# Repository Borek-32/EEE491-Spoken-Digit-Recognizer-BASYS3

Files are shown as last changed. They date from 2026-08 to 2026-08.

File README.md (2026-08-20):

# FPGA MFCC digit recognizer

This repository is the source-and-evidence release of an EEE491 fixed-point
spoken-digit recognizer for the Digilent Basys 3. The design acquires an
external ADC stream and implements the full feature/classification path in
VHDL:

```text
ADC/VAD -> Hann window -> 512-point FFT -> 32-channel Mel bank
        -> log2 approximation -> 8-coefficient DCT -> template comparator
```

The packaged hardware profile is the home-fabricated microphone/ADC board on
Pmod JC. `constraints/jc_homefab.xdc` is the only top-level constraint file in
the release. Generated Vivado projects, checkpoints, bitstreams, logs and
waveform databases are deliberately not versioned.

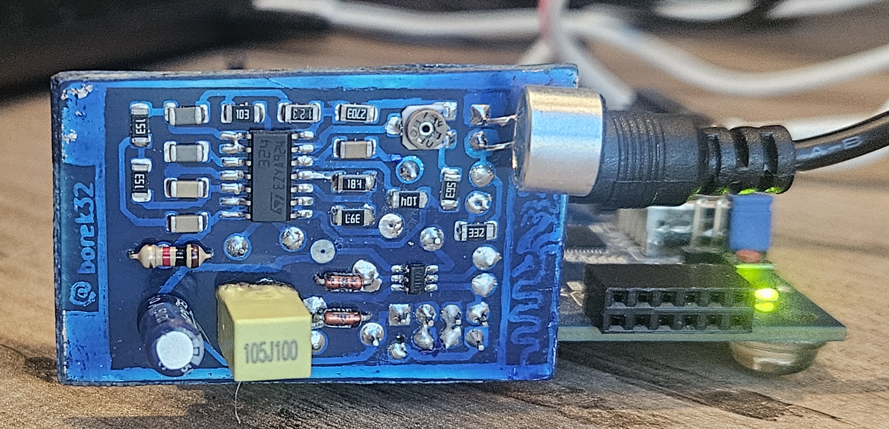
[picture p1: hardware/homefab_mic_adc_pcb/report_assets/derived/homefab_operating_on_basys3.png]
Home-fabricated input board operating with the Basys 3


## What is here

- `rtl/`: the eleven synthesizable VHDL units, with `top_module` as top.
- `testbench/` and `verification/`: eleven VHDL benches, retained fixed-point
  inputs/outputs, MATLAB cross-checks, and a bounded safe regression runner.
- `ip/` and `data/`: twenty AMD IP configuration files and five ROM
  initialization sources. Generated IP products are intentionally absent.
- `constraints/jc_homefab.xdc`: the complete 39-port Basys 3/JC pin profile.
- `hardware/homefab_mic_adc_pcb/`: KiCad sources, photos, verification tools,
  and report figures for the physical microphone/ADC board.
- `hardware/pcb_adc_uart/`: the isolated ADC-to-UART diagnostic and its
  explicitly bounded evidence.
- `implementation/`: retained text reports from the historical main
  run and the final JC-mapped implementation. These reports are evidence, not
  inputs to the clean build.
- `docs/report/EEE491_MFCC_Final_Report_2026-08-20.pdf`: the final project
  report.

## Quick start

Vivado 2025.2 is the reference version. Choose fresh directories outside this
repository; the scripts reject in-tree or pre-existing output directories.
Run Vivado itself from a fresh external runtime directory so journals, logs and
`.Xil` process state never enter the checkout.

```bash
repo_root=$(pwd -P)
build_dir=$(readlink -m ../mfcc-build-v1.0.0)
results_dir=$(readlink -m ../mfcc-results-v1.0.0)
runtime_dir=$(readlink -m ../mfcc-runtime-v1.0.0)
mkdir -- "$runtime_dir"

(
  cd "$runtime_dir"
  vivado -mode batch -notrace \
    -journal "$runtime_dir/01-recreate.jou" \
    -log "$runtime_dir/01-recreate.log" \
    -source "$repo_root/scripts/recreate_project.tcl" \
    -tclargs "$build_dir"

  vivado -mode batch -notrace \
    -journal "$runtime_dir/04-build-jc.jou" \
    -log "$runtime_dir/04-build-jc.log" \
    -source "$repo_root/scripts/build_jc_homefab.tcl" \
    -tclargs "$build_dir" "$results_dir" 4
)
```

The first command copies the release inputs into the external build directory,
creates a new project for `xc7a35tcpg236-1`, and regenerates IP products there.
The second runs synthesis and implementation, validates timing/routing/DRC and
the complete package-pin map, then places reports and a generated bitstream in
the external results directory.

Run the repository integrity and privacy gate with:

```bash
python3 scripts/check_release.py
```

The gate also requires Git's clean-filtered bytes to match the worktree bytes,
so a commit and fresh checkout cannot silently invalidate `SHA256SUMS`.

Or run the complete non-hardware release workflow in fresh external directories:

```bash
scripts/run_release_checks.sh ../mfcc-build-v1.0.0 \
  ../mfcc-results-v1.0.0 --top-smoke --jobs 4
```

`VIVADO_BIN` and `MATLAB_BIN` may name alternate executables. The wrapper runs
the integrity gate, recreation, nine safe XSim benches, optional top smoke,
MATLAB gates, and the full JC build. It creates the fresh external
`../mfcc-results-v1.0.0.runtime/` directory for Vivado process state and never
programs hardware. The MATLAB gate is serialized and refuses to start while
another MATLAB process is active.

See [REPRODUCIBILITY.md](REPRODUCIBILITY.md) for simulation, MATLAB, KiCad and
hardware procedures.

## Verified result and evidence boundary

The retained final JC implementation reports:

- routed setup slack `+0.671 ns` and hold slack `+0.020 ns`;
- 12,824/12,824 routable nets complete, with zero routing errors;
- zero DRC errors, critical warnings, or warnings (11 advisories);
- 5,603 LUTs, 8,437 registers, 23.5 BRAM tiles, and 15 DSPs.

Those are internal FPGA implementation results. The methodology report retains
36 `TIMING-18` warnings because external I/O delays were not characterized;
the ADC board interface is therefore not claimed as board-level timing closed.

The report describes a working bench demonstration and historical recognition
observations. No pre-labeled live session made with the final FFT/Mel-corrected
image was retained, so this release makes no numerical live-accuracy claim.
The earlier 30/30 development set predates those final corrections and is not
presented as final-system accuracy. Photographs show construction and operation;
they do not independently establish recognition accuracy.

The isolated ADC/UART reconstruction closes its declared internal timing, but
its retained CDC report contains 133 `CDC-1` critical findings, 12 `CDC-15`
warnings, and four `CDC-3` informational findings. Its corrected SPI-alignment
candidate passes simulation and implementation; the decisive voltage/UART
endpoint capture remains **NOT RUN**. These boundaries are preserved in the
corresponding hardware documentation.

## Hardware safety and explicit target selection

No script selects a programmer or serial port by a repository-embedded device
identifier. Programming requires both an explicit bitstream path and an
explicit JTAG target substring and the expected bitstream SHA-256. MATLAB
capture requires an explicit UART port, JTAG target identity, bitstream path,
expected SHA-256, programming-log path, and output path.
Inspect the discovered target and wiring before acting; a generated bitstream
or a successful JTAG configuration is not proof of correct analog behavior.

## License and citation

Original source and hardware-design files are released under the MIT License;
portfolio media, the report, retained evidence, and third-party tool/IP
material have the narrower terms described in [NOTICE.md](NOTICE.md). Citation
metadata is in [CITATION.cff](CITATION.cff).

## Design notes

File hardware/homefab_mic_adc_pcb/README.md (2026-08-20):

# Home-fabricated microphone and ADC PCB

This directory documents the physical input board used with the full MFCC
design on 19 August 2026. It combines the microphone front end, analog filter,
ADC121S101 interface, local adjustments, power connection, and a Basys 3 Pmod
connection.

## Retained configuration

- FPGA top: `top_module`
- ADC mapping: JC3/N17 `spi_clk`, JC4/P18 `spi_miso`, JC9/P17 `cs_out`
- Full debug stream: Basys 3 USB-UART TX on A18 at 1,000,000 baud
- Canonical constraint: `../../constraints/jc_homefab.xdc`
- Routed implementation evidence: `../../implementation/jc_homefab/`
- Photographs: `photos/`
- Reconciled board source and checks: `kicad/`
- Metadata-free report figures and generator: `report_assets/`

No bitstream or programming log is versioned. Build a fresh bitstream outside
the repository and pass its path, SHA-256 and an explicitly inspected JTAG
target substring to `programming/program_full_mfcc_jc.tcl`.

## Recognition evidence boundary

Bench operation and near-perfect informal recognition were observed during
development, but no pre-labeled live session made with the final FFT/Mel-
corrected image was retained. This release therefore makes no numerical
final-system accuracy claim. The logger under `../../verification/hardware/`
can create a new declared session, but a future run is new evidence and is not
retroactively part of the final report.

## KiCad boundary

The reconciled schematic and PCB share the same exact set of 21 named nets.
KiCad's native connectivity accounts for 75 pads, 287 track segments and 18
vias; one isolated Pmod pad intentionally remains no-net. The home-fabricated
copper is mirrored relative to logical ADC121S101 and LM324 footprint numbering,
as documented in `kicad/README.md`.

Net reconciliation passes, but fab-ready closure is not claimed. The retained
PCB DRC has 12 errors and 114 warnings; schematic ERC has 8 errors and 20
warnings. JC10/R18 is also driven by the FPGA `pmod` output and must remain
physically isolated from an unintended board connection.

## Photograph provenance

The eleven retained photographs cover the July-to-August fabrication sequence.
The repository copies were auto-oriented and stripped of EXIF/GPS metadata.
The July defective UV trial is explicitly development evidence; later operating,
component-side and solder-side images document the final populated board.
Photographs do not independently establish electrical behavior or recognition
accuracy.

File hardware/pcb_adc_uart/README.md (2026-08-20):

# Standalone PCB ADC-to-UART diagnostic

This directory isolates the recovered `PCB.vhd` diagnostic from the MFCC
recognizer. Top `PCB` reads the external SPI ADC, averages 32 conversions,
recenters the 12-bit samples, and transmits signed 16-bit values over the
Basys 3 USB-UART connection.

## Reproducible inputs

- `src/PCB.vhd`: recovered baseline RTL, SHA-256
  `751c59a1592b73d9a1a77779d09f4339b96f97ef051685ae126386492618f96f`
- `constraints/pcb_adc_uart_basys3.xdc`: standalone JC constraints
- `ip/clk_wiz_0/clk_wiz_0.xci`: 100 MHz to 36 MHz Clocking Wizard metadata
- `recreate_project.tcl` and `build_and_verify.tcl`: out-of-tree interfaces
- `build_evidence/`: retained text reports from the 19 August reconstruction
- `trials/adc121s101_spi_alignment_20260819/`: preserved baseline/candidate
  source comparison and explicitly bounded evidence

Generated XPR, IP products, DCP, bitstream, log and cache files are excluded.

## Recreate and build

Choose fresh directories outside the public repository:

```bash
vivado -mode batch -notrace -source recreate_project.tcl \
  -tclargs ../../../../pcb-adc-build
vivado -mode batch -notrace -source build_and_verify.tcl \
  -tclargs ../../../../pcb-adc-build ../../../../pcb-adc-results 4
```

An optional second recreation argument selects an explicit RTL file. This is
how the retained SPI-alignment candidate can be rebuilt without replacing the
baseline source:

```bash
vivado -mode batch -notrace -source recreate_project.tcl \
  -tclargs ../../../../pcb-adc-candidate-build \
  trials/adc121s101_spi_alignment_20260819/candidate/PCB.vhd
```

The scripts refuse in-tree or pre-existing output directories. The build gate
checks routed setup/hold timing, complete routing, DRC, methodology, the 100 MHz
and 36 MHz clocks, and the exact eight-port package-pin map. A generated
bitstream is copied only to the external results directory.

## Retained reconstruction result

Vivado 2025.2 reported WNS `+6.899 ns`, WHS `+0.131 ns`, all 203 routable nets
complete, and zero DRC/methodology findings. That is internal implementation
evidence, not complete hardware validation. The external SPI ports have no
ADC-datasheet-derived input/output delays.

The retained CDC report still contains 133 `CDC-1` critical findings, 12
`CDC-15` warnings and four `CDC-3` informational findings for asynchronous
buttons/reset and the handshake-held sample transfer. This recovered design is
not claimed CDC-clean. Hardware capture was not rerun for the reconstruction.

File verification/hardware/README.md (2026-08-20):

# Live MFCC hardware capture

These MATLAB functions parse the `top_module` debug protocol at 1,000,000 baud.
They are distinct from the standalone 921,600-baud ADC/UART diagnostic.

No final labeled accuracy session is included. To create a new session, first
build and program a fresh JC bitstream, retain the programming transcript, and
provide every machine-specific value explicitly:

```matlab
cd('verification/hardware')
run_live_accuracy_session(10, uartPort, jtagTarget, bitPath, ...
    expectedBitSha256, programmingLogPath, evidenceOutputDirectory)
```

The launcher requires a nonempty UART port and JTAG target identity, verifies
the exact bitstream hash, checks a recent PASS programming record, and refuses
post-result retries. It pre-generates a balanced randomized schedule of 100
declared trials (ten per digit) by default. For each prompt, the operator arms
the UART and then starts one spoken-digit acquisition.

A completed session contains the schedule and metadata, raw bytes and decoded
MAT data for each trial, append-after-every-trial CSV, per-digit metrics, a
confusion matrix with a separate protocol-failure column, a summary, logger
source snapshot, programming provenance, lifecycle index, and SHA-256 manifest.
The primary metric is correct/planned; conditional correct/protocol-complete and
transport completion are reported separately.

Run the non-hardware evidence-path self-test with:

```matlab
run_live_accuracy_session("selftest")
```

Each live trial contains 63 frames. Each frame contains 1,362 big-endian 32-bit
words: marker/address/COMP status, 512 ADC words, 512 WINDOW words, 256 FFT
words, 32 MEL words, 32 LOGMEL words, eight DCT words, and the end marker. The
decision is accepted only from frame address 15,872.

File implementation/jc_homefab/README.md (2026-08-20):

# Retained JC/home-fabricated-board implementation evidence

This directory contains sanitized text evidence from the isolated Vivado 2025.2
implementation completed on 19 August 2026. The public build input is
`../../constraints/jc_homefab.xdc`; the reports here are not consumed during a
clean rebuild.

## Pin profile

| Signal | Basys 3 contact | Package pin | Direction |
| --- | --- | --- | --- |
| `spi_clk` | JC3 | N17 | output |
| `spi_miso` | JC4 | P18 | input |
| `cs_out` | JC9 | P17 | output |

The XDC is a complete 39-port profile, not an overlay. JC10/R18 remains driven
by the separate `pmod` output and must be physically isolated unless a future
board revision makes that connection intentionally compatible.

## Retained result

- Top `top_module`, part `xc7a35tcpg236-1`
- Implementation through `write_bitstream`: complete
- WNS `+0.671 ns`; WHS `+0.020 ns`
- 12,824/12,824 routable nets routed; zero routing errors
- DRC: 0 errors, 0 critical warnings, 0 warnings, 11 advisories
- 5,603 LUTs, 8,437 registers, 23.5 BRAM tiles, 15 DSPs
- All 39 scalarized ports constrained exactly once

The public release excludes the generated `.bit`, routed `.dcp`, Vivado logs,
IP-status dump, and original-tree protection hashes. Rebuild with
`../../scripts/recreate_project.tcl` and `../../scripts/build_jc_homefab.tcl`;
generated results remain outside the checkout.

## Evidence boundary

This is an internal FPGA implementation PASS. It is not external ADC timing
closure or a standalone hardware-function proof. The methodology report retains
36 `TIMING-18` warnings for 18 inputs and 18 outputs without I/O delays. The
full MFCC design also retains the legacy ADC receiver; the isolated diagnostic's
corrected SPI candidate is not silently substituted here.

Machine-local command paths in these retained text reports were replaced with
`<isolated-build>` for publication. Numerical findings and report bodies were
otherwise retained.

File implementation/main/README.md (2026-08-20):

# Historical main implementation reports

These four text reports preserve the routed result from the finalized main
project before public-repository reconstruction. They record WNS `+0.630 ns`,
WHS `+0.014 ns`, complete routing, and routed DRC/utilization data.

No corresponding baseline constraint file is packaged: the only public build
profile is `../../constraints/jc_homefab.xdc`. These reports are historical
evidence, not inputs to `scripts/recreate_project.tcl`, and must not be read as
proof of ADC board-level timing because 36 `TIMING-18` missing-I/O-delay
warnings remain in the timing summary.

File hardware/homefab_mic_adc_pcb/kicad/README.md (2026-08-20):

# Reconciled KiCad source

This directory contains the report-ready schematic and the recovered PCB with
every routed copper island assigned its schematic net name; the one physically
isolated, unused Pmod pad is explicitly retained as `<no net>`.

- `mfcc_homefab_named_nets.kicad_sch`: schematic with the ADC ground joined to
  the existing global `GND` net.
- `mfcc_homefab_named_nets.kicad_pcb`: original board geometry with net names
  added to all pads, routed segments, and vias.
- `mfcc_homefab_named_nets.kicad_pro`: KiCad project settings generated for the
  reconciled pair.
- `tools/`: fail-closed reconstruction and verification scripts.
- `evidence/`: exported netlist, IPC-D-356 netlist, native KiCad checks,
  hashes, and the inspected schematic render.

The pre-reconciliation source copies are retained under `originals/`. Their
SHA-256 values are:

- schematic: `e35c51a3030d64c75fbf8b99cae6bb0e8106192cca6c8ed2968b3d3029f0215c`
- PCB: `d63a80d06c6ad783caed415275df6e86c6c870cf5f2c0cff97cd489689012f88`

## Exact net reconciliation

KiCad 10.0.3 native connectivity found 22 physical copper islands. Twenty-one
use the exact exported schematic names; the remaining island is an intentionally
isolated Pmod pad and remains `<no net>`.

| Island | Exact net | Pads | Segments | Vias |
| --- | --- | ---: | ---: | ---: |
| I001 | `/ref` | 4 | 12 | 0 |
| I002 | `/3v3` | 4 | 26 | 3 |
| I003 | `/JC9` | 2 | 33 | 4 |
| I004 | `GND` | 12 | 50 | 3 |
| I005 | `<no net>` | 1 | 0 | 0 |
| I006 | `/JC4` | 3 | 9 | 2 |
| I007 | `VCC` | 5 | 33 | 2 |
| I008 | `/JC3` | 2 | 4 | 1 |
| I009 | `/filter-out` | 4 | 13 | 1 |
| I010 | `/div-ref` | 4 | 14 | 0 |
| I011 | `/mic` | 3 | 15 | 2 |
| I012 | `/ss2r` | 3 | 6 | 0 |
| I013 | `/div-out` | 3 | 8 | 0 |
| I014 | `/ss2c` | 3 | 8 | 0 |
| I015 | `/amp1` | 3 | 10 | 0 |
| I016 | `/pot1` | 2 | 6 | 0 |
| I017 | `/ss1c` | 3 | 8 | 0 |
| I018 | `/ss1o` | 4 | 10 | 0 |
| I019 | `/amp2` | 2 | 7 | 0 |
| I020 | `/amp-out` | 3 | 4 | 0 |
| I021 | `/ss1r` | 3 | 8 | 0 |
| I022 | `/pot2` | 2 | 3 | 0 |

The exported schematic contains exactly these 21 named nets, and the named PCB
contains the same 21-name set. Coverage is complete: 75 pads, 287 track
segments, and 18 vias are accounted for. The before/after structured geometry
fingerprints are identical.

## Home-fabrication mirror

The successful physical board is mirrored relative to the logical pad numbers
in the recovered footprints. Net assignment therefore follows the working
electrical pins, not the printed geometric pad numbers.

ADC footprint geometry maps to the
[TI ADC121S101 pinout](https://www.ti.com/lit/ds/symlink/adc121s101.pdf)
as follows:

| Geometric pad | Actual ADC pin/function | Net |
| ---: | --- | --- |
| 1 | 3, `VIN` | `/ref` |
| 2 | 2, `GND` | `GND` |
| 3 | 1, `VA` | `/3v3` |
| 4 | 6, `/CS` | `/JC9` |
| 5 | 5, `SDATA` | `/JC4` |
| 6 | 4, `SCLK` | `/JC3` |

For the SO-14 LM324, the actual lead is `15 - geometric pad`. This places the
actual positive supply on geometric pad 11 (`VCC`) and the actual negative
supply on geometric pad 4 (`GND`), and it resolves all four amplifier stages.
The two recovered board diode references are also reversed by role relative to
the schematic; the net assignment follows the electrical clamp nodes.

## Ground correction

The source schematic used both the global `GND` net and a local `/gnd` label
for the ADC. The fabricated PCB has one common ground island. The reconciled
schematic therefore replaces only that local label with a wired global GND
symbol. It now exports one `GND` net and no `/gnd` or anonymous ADC-ground net.

## Verification boundary

`evidence/bundle_validation.json` records `PASS_NET_ASSIGNMENT`:

- 21/21 schematic names equal 21/21 named PCB nets;
- all pads, tracks, and vias are assigned to their native KiCad island;
- one isolated Pmod pad is deliberately left no-net;
- no board geometry changed;
- KiCad DRC reports zero unconnected items.

This does **not** make the legacy home-fabrication layout DRC-clean. The retained
DRC contains 126 inherited findings: 12 errors and 114 warnings, including two
copper-clearance findings, malformed/co-located Pmod holes, courtyard overlaps,
a missing formal `Edge.Cuts` outline, and dangling legacy stubs. The schematic
ERC retains 28 pre-existing structural findings (8 errors and 20 warnings),
principally because the drawing models four op-amp triangles as separate
references rather than one multi-unit LM324 package and omits connector/power
driver detail. These limitations are preserved rather than hidden.

The direct Pmod footprint also joins the geometric contacts corresponding to
JC4 and JC10. The full FPGA design still drives JC10 as a separate `pmod`
output, so that contact must remain physically unpopulated/isolated or the FPGA
constraint must be disabled before treating a future revision as fab-ready.

## Reproduce the checks

Run the net assignment with KiCad's Python runtime:

```bash
flatpak run --command=python3 org.kicad.KiCad \
  tools/assign_schematic_nets.py SOURCE.kicad_pcb OUTPUT.kicad_pcb \
  --manifest evidence/net_assignment_manifest.json
```

Then export the schematic netlist/ERC and PCB DRC with `kicad-cli`, and run:

```bash
python3 tools/verify_named_bundle.py . \
  --desktop-schematic originals/mfcc.kicad_sch \
  --desktop-board originals/mfccsmd.kicad_pcb \
  --output evidence/bundle_validation.json
```

`PASS_NET_ASSIGNMENT` is deliberately narrower than fabrication approval. The
retained 126 PCB DRC and 28 schematic ERC findings remain open. Machine-local
paths in the exported evidence were replaced with repository-relative names;
the visible `borek32` copper marking is retained as intentional attribution.

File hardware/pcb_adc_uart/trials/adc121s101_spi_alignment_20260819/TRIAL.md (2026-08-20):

# ADC121S101 SPI-alignment trial (19 August 2026)

## Status

**Simulation PASS; implementation PASS; historical JTAG configuration PASS;
ADC endpoint capture NOT RUN.** This isolated diagnostic did not modify the
full MFCC `rtl/ADC.vhd`.

## Hypothesis and candidate

Bench observations near -2048 counts at 0 V but near 0 around the ADC supply
were consistent with a lost most-significant bit. The recovered receiver made
CS and the first falling SCLK edge coincide, did not explicitly retain a full
16-edge frame, and could sample before the ADC's worst-case access time.

The candidate in `candidate/PCB.vhd` asserts CS before the first transition,
captures exactly 16 falling edges, keeps the final 12 straight-binary bits,
discards the first completed conversion after start, averages the next 32, and
subtracts 2048 once. Its SHA-256 is
`a0171a70c302a14324324ea2dcbe9c7db5a120b0992fcf97e270fb91682063c6`.
The baseline source SHA-256 is
`751c59a1592b73d9a1a77779d09f4339b96f97ef051685ae126386492618f96f`.

## Retained results

The purpose-built model used worst-case 3.3 V `tACC=40 ns`, optional leading
zero phase behavior, exact 16-edge framing, a nontrivial discarded frame, and
six 32-frame endpoint groups. The candidate returned centered values `-2048,
-2047, -1, 0, 1, 2047` for raw codes `000, 001, 7FF, 800, 801, FFF`; the
baseline failed the same checks. See `results/SIMULATION_RESULTS.md`.

The retained Vivado 2025.2 reports show WNS `+6.874 ns`, WHS `+0.106 ns`,
192/192 routable nets complete, zero DRC/methodology findings, the 100 MHz and
36 MHz clocks, and the JC mapping N17/P18/P17. External ADC input timing remains
unclosed, and inherited CDC findings remain disclosed.

Historical evidence recorded successful FPGA configuration of the candidate.
The public release removes the machine-specific JTAG identity, programming log,
bitstream, checkpoint and waveform/log products. A repeat must rebuild the
candidate, supply an explicit target and hash to `hardware/program_candidate.tcl`,
and retain new evidence outside the checkout.

## Evidence boundary

No measured `VA`, `Vin`, or raw UART endpoint capture was retained. Functional
ADC validation is therefore **NOT RUN**, not inferred from simulation,
implementation, or JTAG configuration. The decisive future measurements remain
0 V, measured midscale, and approximately `VA - 50 mV`, following
`results/HARDWARE_TEST_PROCEDURE.md`.

The timing/framing criteria follow the TI ADC121S101 Rev. H datasheet, especially
Figure 2 and Sections 8.3, 8.3.1, 8.3.2, and 8.4.2.

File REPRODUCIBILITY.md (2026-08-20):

# Reproducibility guide

This release separates reproducible inputs from retained historical evidence.
The clean scripts create all Vivado state outside the repository. Existing
reports under `implementation/` are never consumed by the build.

## Reference environment

The release was curated against:

- AMD Vivado 2025.2, build 6299465, IP build 6300035;
- MATLAB R2025b Update 5 (`25.2.0.3177638`);
- KiCad 10.0.3;
- Git 2.53.0;
- Python 3.14.4.

The FPGA part is `xc7a35tcpg236-1`. The clean Vivado recreation does not depend
on an installed Basys 3 board-part definition.

## 1. Verify the release

From the repository root:

```bash
python3 scripts/check_release.py
```

This checks the allowlisted source counts, required files, absence of generated
Vivado products and private machine identifiers, KiCad evidence boundary, Git
clean-filter byte stability for every manifest candidate, and every entry in
`SHA256SUMS`. Run it from a Git working tree so `.gitattributes` can be applied.
Maintainers may regenerate the portable manifest only after an intentional
content change:

```bash
python3 scripts/check_release.py --write-checksums
python3 scripts/check_release.py
```

Paths in `SHA256SUMS` are sorted repository-relative POSIX paths. The manifest
does not include itself or `.git/`.

### Complete non-hardware workflow

The documented steps below are also available through one fail-closed wrapper:

```bash
scripts/run_release_checks.sh ../mfcc-build-v1.0.0 \
  ../mfcc-results-v1.0.0 --top-smoke --jobs 4
```

`--top-smoke` is opt-in; omit it to retain an explicit `TOP_SMOKE=NOT_RUN`
boundary. Set `VIVADO_BIN=/path/to/vivado` or `MATLAB_BIN=/path/to/matlab` to
override the default `vivado` and `matlab` commands. Both supplied output paths
and the derived `RESULTS_DIR.runtime` path must be fresh and outside the
repository. The wrapper keeps Vivado's journals, logs and `.Xil` process state
in that runtime directory. It also refuses to overlap the MATLAB gate with an
existing MATLAB process and serializes concurrent wrapper invocations with a
per-user runtime lock. Physical programming is never part of this workflow.

## 2. Recreate the full JC project

Choose build, results and process-runtime paths outside the checkout that do
not already exist. The standalone commands in the following sections share
these absolute shell variables:

```bash
repo_root=$(pwd -P)
build_dir=$(readlink -m ../mfcc-build-v1.0.0)
results_dir=$(readlink -m ../mfcc-results-v1.0.0)
runtime_dir=$(readlink -m ../mfcc-runtime-v1.0.0)
mkdir -- "$runtime_dir"

(
  cd "$runtime_dir"
  vivado -mode batch -notrace \
    -journal "$runtime_dir/01-recreate.jou" \
    -log "$runtime_dir/01-recreate.log" \
    -source "$repo_root/scripts/recreate_project.tcl" \
    -tclargs "$build_dir"
)
```

The script copies `rtl/`, `testbench/`, `constraints/` and `verification/` into
`../mfcc-build-v1.0.0/`. It stages byte-for-byte `ip/` and `data/`
under the external compatibility path
`../mfcc-build-v1.0.0/mfcc-recog 1.4.srcs/sources_1/`; Vivado validates that
original XCI customization context and the relative COE paths. It then creates
a fresh project, sets VHDL 2008, adds only `constraints/jc_homefab.xdc`, and
reapplies each resolved COE path plus the defining multiplier and FFT
customizations through Vivado's IP API to initialize fresh model state. Vivado
writes the same relative COE values back into the external XCI copies before
regenerating IP. The script refuses to overwrite an existing directory or
build inside the repository.

## 3. Run the bounded behavioral regression

After project recreation:

```bash
(
  cd "$runtime_dir"
  vivado -mode batch -notrace \
    -journal "$runtime_dir/02-safe-testbenches.jou" \
    -log "$runtime_dir/02-safe-testbenches.log" \
    -source "$repo_root/verification/run_testbenches.tcl" \
    -tclargs "$build_dir"
)
```

The default safe set is `tb_CTRL`, `tb_debug`, `tb_WINDOW`, `tb_FFT`, `tb_MEL`,
`tb_LOGMEL`, `tb_DCT`, `tb_comp`, and `tb_seven_segment`. Each bench is bounded
to 20 ms simulated time, and the runner scans XSim's transcript before printing
PASS. `tb_ADC` is rejected by this interface because its long acquisition run
needs an explicitly monitored workflow. `tb_top_module` remains opt-in:

```bash
(
  cd "$runtime_dir"
  vivado -mode batch -notrace \
    -journal "$runtime_dir/03-top-smoke.jou" \
    -log "$runtime_dir/03-top-smoke.log" \
    -source "$repo_root/verification/run_testbenches.tcl" \
    -tclargs "$build_dir" tb_top_module
)
```

Testbench outputs are written beneath the external project's
`verification/tb_output/`, not into the checkout.

Run the matching MATLAB fixed-point checks against that external snapshot:

```bash
matlab_lock=${XDG_RUNTIME_DIR:-/tmp}/mfcc-release-matlab-$(id -u).lock
matlab_log="$runtime_dir/matlab-safe.log"
(
  set -euo pipefail
  if ! flock -n 9; then
    echo "another MFCC release MATLAB gate is active" >&2
    exit 2
  fi
  if pgrep -x MATLAB >/dev/null 2>&1; then
    echo "another MATLAB process is active; wait before running this gate" >&2
    exit 2
  fi
  cd "$build_dir"
  if ! matlab -batch \
    "run('verification/matlab/run_safe_module_verifiers.m'); diary('off'); clear cleanup_diary cleanup_state; fprintf('MATLAB_CALLER_CLEANUP_PASS\n');" \
    2>&1 | tee "$matlab_log"; then
    echo "MATLAB verification process failed" >&2
    exit 1
  fi
  grep -Fqx 'SAFE_MODULE_VERIFIERS_PASS count=9' "$matlab_log"
  grep -Fqx 'MATLAB_CALLER_CLEANUP_PASS' "$matlab_log"
) 9>"$matlab_lock"
```

The FFT checker uses the AMD bit-accurate model packaged with Vivado. Source
the Vivado settings script first, set `VIVADO_ROOT=/path/to/Vivado`, or use the
complete wrapper, which infers that root from an explicit `VIVADO_BIN` path.
The post-`run` cleanup must remain in the batch caller: MATLAB R2025b can abort
during process teardown if the suite's cleanup guards survive that boundary.
The process must exit zero and emit both required PASS markers. Do not run
another MATLAB process concurrently with this verification workload.

The retained `verification/tb_output/` files are historical reference evidence.
A fresh regression should be judged from the external build snapshot.

## 4. Synthesize, implement and validate

Use the fresh results path declared in step 2:

```bash
(
  cd "$runtime_dir"
  vivado -mode batch -notrace \
    -journal "$runtime_dir/04-build-jc.jou" \
    -log "$runtime_dir/04-build-jc.log" \
    -source "$repo_root/scripts/build_jc_homefab.tcl" \
    -tclargs "$build_dir" "$results_dir" 4
)
```

The optional final argument is the positive Vivado job count. The script:

1. resets and runs synthesis and implementation through `write_bitstream`;
2. writes timing, routing, DRC, methodology, utilization, I/O, clocks, CDC and
   timing-check reports outside the repository;
3. requires non-negative routed setup and hold slack;
4. requires every routable net to be routed;
5. rejects DRC error, critical-warning, or warning severity;
6. validates the exact 39-port package-pin dictionary and the 100 MHz clock;
7. copies the generated `.bit` only to the external results directory.

The external-interface limitation remains: the XDC constrains the internal
100 MHz clock but contains no ADC-datasheet-derived input/output delays.

## 5. KiCad evidence

The public `kicad/originals/` copies and reconciled pair are sufficient to rerun
the net assignment and verification. The visible decorative copper username is
retained as intentional public attribution; machine-local filesystem paths are
sanitized. See the directory README for commands and exact limits.

KiCad's Python runtime can rebuild the named-net PCB:

```bash
cd hardware/homefab_mic_adc_pcb/kicad
flatpak run --command=python3 org.kicad.KiCad \
  tools/assign_schematic_nets.py \
  originals/mfccsmd.kicad_pcb mfcc_homefab_named_nets.kicad_pcb \
  --manifest evidence/net_assignment_manifest.json
```

Run the fail-closed bundle verifier after exporting current KiCad netlist,
ERC, DRC and render artifacts as described in the local README:

```bash
python3 tools/verify_named_bundle.py . \
  --desktop-schematic originals/mfcc.kicad_sch \
  --desktop-board originals/mfccsmd.kicad_pcb \
  --output evidence/bundle_validation.json
```

`PASS_NET_ASSIGNMENT` means exact net-name coverage only. It is not a claim of
fab-ready DRC/ERC closure.

## 6. Hardware programming and capture

Build first, then inspect the live hardware target. Programming is deliberately
separate from implementation and is never performed by the build script:

```bash
(
  cd "$runtime_dir"
  vivado -mode batch -notrace \
    -journal "$runtime_dir/05-program-jc.jou" \
    -log "$runtime_dir/05-program-jc.log" \
    -source "$repo_root/hardware/homefab_mic_adc_pcb/programming/program_full_mfcc_jc.tcl" \
    -tclargs "$results_dir/top_module_jc_homefab.bit" \
    YOUR_EXPLICIT_JTAG_TARGET_SUBSTRING \
    YOUR_EXPLICIT_64_HEX_BITSTREAM_SHA256
)
```

The programming script requires and validates the selected bitstream's SHA-256.
It requires exactly one target match and exactly one `xc7a35t` device.

For a new labeled accuracy session, call MATLAB with all environment-specific
inputs. The output directory must be fresh and outside the repository:

```matlab
run_live_accuracy_session(10, uartPort, jtagTarget, bitPath, ...
    expectedBitSha256, programmingLogPath, evidenceOutputDirectory)
```

No retained final-system session is shipped. A newly generated session is new
evidence and must not be confused with the historical claims in the report.

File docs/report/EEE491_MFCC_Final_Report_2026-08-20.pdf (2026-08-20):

EEE491 ENGINEERING PROJECT REPORT

# FPGA-Based MFCC Spoken Digit Recognition

## A fixed-point audio feature-extraction and template-matching system for the Basys 3

Author: Kerem Gürbüz
Bilkent University, Department of Electrical and Electronics Engineering Target device: Digilent Basys 3 / xc7a35tcpg236-1 Project scope: RTL, verification, FPGA integration, and home-fabricated microphone/ADC PCBs Design language: VHDL
Tool flow: Vivado 2025.2, XSim, MATLAB Design baseline: implemented and routed Basys 3 system Repository: https://github.com/Borek-32/EEE491-Spoken-Digit-Recognizer-BASYS3 Final report - 20 August 2026

The report follows the complete path from signal acquisition to fixed-point recognition and physical prototyping.

FPGA MFCC Spoken Digit Recognition - EEE491

## Abstract

I built a fixed-point spoken-digit recognizer for the Digilent Basys 3. The design records 16,384 ADC samples, processes 63 overlapping frames, and extracts eight DCT coefficients using Hann windowing, a 512-point FFT, 32 MEL filters, and fixed-point log compression. In record mode, the FPGA writes a selected 16-frame feature sequence into writable reference RAM; in compare mode, a SAD/L1 engine searches the stored templates. A configuration-time seed containing 30 default templates allows immediate comparison before speaker-specific slots are recorded. The non-ADC stages are checked with XSim and integer models, and the current routed design meets the internal 100 MHz constraint. A 30-utterance development set separates 30/30 in leave-one-out testing, but those recordings predate the final FFT/MEL address corrections and are not a live-speaker accuracy result. I also designed and fabricated the microphone front-end PCB. On 19 August 2026 I also integrated a later home-fabricated microphone/ADC PCB through Pmod JC, programmed the corresponding full-design bitstream, and observed live recognition. Because no pre-labeled trial session was retained, I report that result as a functional bench observation rather than a numerical hardware accuracy claim. Keywords: FPGA; MFCC; fixed-point DSP; spoken digit recognition; VHDL; UART debugging.

## Contents

1 | Introduction and Project Objective | 4
2 | Design Boundary and Evidence Strategy | 6
3 | Hardware Platform and User Operation | 7
4 | System Architecture and Data Contracts | 8
5 | CTRL: Pipeline Orchestration | 10
6 | ADC: Acquisition, Averaging, and Voice Detection | 13
7 | WINDOW: Frame Extraction and Hann Multiplication | 16
8 | FFT: AXI4-Stream Transform and Power Spectrum | 18
9 | MEL: Perceptual Filter-Bank Accumulation | 22
10 | LOGMEL: Piecewise Logarithmic Compression | 26
11 | DCT: Eight-Coefficient Feature Compression | 30
12 | COMP: Runtime Enrollment, Active-Window Selection, and Template Matching | 32
13 | DEBUG: UART Observability | 41
14 | Seven-Segment Display and Top-Level Integration | 42
15 | Verification Methodology and Module Results | 44
16 | Programmed-Board Debugger Demonstration | 45
17 | Retained FPGA-Computed Spoken-Digit Outputs and Separability Results | 53
18 | Vivado Implementation and Clock Engineering | 62
19 | Analog Front End and PCB Development | 64
20 | Discussion, Limitations, and Conclusion | 87
21 | References | 90
A | Supplementary Testbench Views | 91
B | Complete Programmed-Board Tone Evidence | 97
C | Evidence Labels and Reproduction Guide | 111

## 1 Introduction and Project Objective

This project asked me to implement spoken-digit recognition on an FPGA, including acquisition, frame control, feature extraction, template comparison, board controls, display, and debugging. I also built the microphone front end. The report follows the signal through the hardware and explains the main design choices, bugs, verification results, and remaining limitations.
The aim is not precision spectral measurement. It is to retain enough time-varying spectral information to distinguish digits, select a useful 16-frame interval, record it under a digit/trial label, and compare later utterances against the writable references. Runtime enrollment matters because voices, speaking style, microphone placement, and gain vary between users. The digital interfaces still have exact contracts: every WINDOW sample must reach the FFT once, FFT bin k must be stored at address k, and MEL must multiply P[k] by H[m,k].

## 1.1 Project overview

The complete system combines the microphone front end, utterance acquisition, fixed-point feature extraction, and runtime template handling. The first diagram shows that end-to-end path; the second expands only the digital signal-processing chain.

Figure 1. End-to-end project overview from microphone input to runtime enrollment or digit recognition.

Figure 2. Expanded digital feature path from the stored utterance to comparison or reference recording.
After voice detection, centered samples are assembled into a fixed 16,384-word utterance buffer. Sixty-three overlapping frames pass through Hann windowing, FFT/power, MEL, log-MEL, and DCT. COMP uses MEL energy to align a 16-frame DCT sequence, then either overwrites the selected reference slot in record mode or evaluates SAD/L1 distance against the stored templates in compare mode.

Table 1. Project objectives, implemented responses, and the evidence that supports them.

Objective | Implemented response | Evidence used
Acquire a repeatable utterance | 12-bit SPI, 32-conversion average, preroll, VAD, fixed 16,384-sample RAM | ADC waveform and programmed-board captures
Extract speech features | 63 frames; WINDOW, FFT, MEL, LOGMEL, DCT | Raw XSim, integer checkers, and UART stage plots
Enroll speaker-specific templates | Writable COE-initialized reference RAM; digit/trial-selected 16-frame overwrite | Focused COMP simulation records digit 2/trial 1 and recalls digit 2 afterward
Recognize 0-9 | 30 references; 16 frames x 8 coefficients; SAD/L1 | COMP checker and 30-record leave-one-out analysis
Remain observable | Marker-framed 1 Mbaud UART export of all major memories | 1,362-word packet check and live captures
Operate as physical hardware | Basys 3 controls, display, external ADC, custom analog PCB | Routed reports, UI verification, and fabrication evidence

## 2 Design Boundary and Evidence Strategy

Verification combines RTL inspection, XSim timing waveforms, integer-model comparisons, programmed-board UART captures, routed Vivado reports, and PCB evidence. Each source answers a different question, so simulation, numerical checking, implementation reports, and physical-board results are kept separate.
The evidence is used at the boundary it actually checks. A waveform can show transaction order, an integer comparison can check fixed-point words, and a programmed-board capture can show that memories were populated by acquired data. None of those is treated as a substitute for a labeled, post-correction live recognition trial.
Unless stated otherwise, the explanatory diagrams were drawn from the implemented RTL states, ports, widths, and address equations.
Table 2. Evidence types and the engineering question assigned to each one.
Evidence family | Question answered | Interpretation rule
RTL and constraints | What is implemented? | Used for algorithms, states, widths, addressing, and the record/flush control paths
XSim waveform | Did the hardware transaction occur in the intended order? | Read for handshakes, latency, addressing, and writes; not treated as a numerical accuracy claim alone
MATLAB checker | Do saved words match the intended fixed-point model? | Used for exact word comparisons and explained implementation/model differences
UART capture | Did a programmed FPGA populate the complete signal chain? | Used for continuity, frequency localization, stage-memory population, framing, and result serialization
Routed reports | Does the integrated design fit and close timing? | Used for implementation feasibility, not as a substitute for functional explanation
PCB evidence | Was the analog path designed and physically produced? | Simulation and fabrication are identified separately; no unrecorded measurement is implied

## 3 Hardware Platform and User Operation

The target is the Digilent Basys 3 with the XC7A35T device and a 100 MHz board clock [3]. The FPGA receives external ADC data, stores an utterance, runs the feature chain, and either records a labeled speaker-specific reference or compares the utterance with the writable reference memory. A COE seed supplies 30 repeatable startup templates; runtime enrollment overwrites any selected digit/trial slot. Switches and buttons select the mode, label, trial, debug path, and reference-memory maintenance, while LEDs and the four-digit display show progress and the final result.
Table 3. Board controls and their role in a complete record or compare experiment.
Control or interface | Implemented behavior
SW0 | High selects runtime enrollment; low selects compare mode. The synchronized start edge captures the selection for the complete 63-frame run.
SW1 / LD1 | Enables the per-frame UART debugger; LD1 mirrors the debug-enable state.
SW6-SW15 | One-hot reference digit selection from 0 through 9 for record mode.
BTNU | Starts one acquisition through edge detection; holding the button does not retrigger continuously.
BTNL / BTNR | Select trial 0, 1, or 2 through synchronized, debounced inputs.
BTND | Requests volatile reference-RAM flush while the complete controller is ready; requests during an active run are gated off.
BTNC | Resets the integrated system.
Seven-segment display | Record view: r d digit trial. Compare view: C d d result after a valid decision.
ADC pins | Registered chip select, MISO, and SCLK connect the external 12-bit converter.

This interface is not the central technical contribution, but it makes speaker adaptation possible without resynthesizing or regenerating the COE. At the synchronized start edge the top level captures record/compare mode, digit, and trial into run registers; later switch or button changes therefore cannot relabel an utterance or change its operation midway through the 63-frame transaction. The debug path is optional because full-memory UART export is intentionally slower than the normal enrollment or recognition path.

## 4 System Architecture and Data Contracts

The recognizer is divided into RAM-separated stages. Each module owns one operation, lowers ready while working, writes a complete local result, and raises ready when the next stage may safely read it. The memories absorb unequal BRAM, multiplier, FFT-IP, and UART latencies while keeping the fixed-point path observable.

Figure 3. Processing pipeline and stored data dimensions. The data contract becomes progressively smaller: 16,384 signed samples become 63 overlapping frames, each frame becomes 256 one-sided power values, then 32 perceptual bands, and finally eight signed DCT coefficients. The reduction is purposeful: COMP does not need analyzer-grade spectral detail; it needs a compact sequence that retains the speech envelope and can be compared repeatedly with modest hardware.

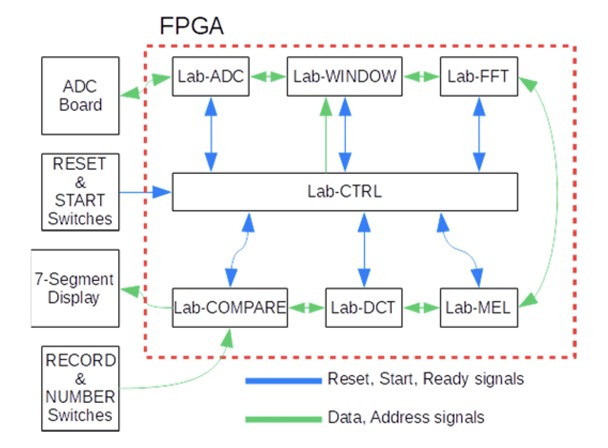
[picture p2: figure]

Figure 4. Original laboratory milestone architecture retained from the earlier report. Historical design-stage diagram extracted from the earlier report. This earlier diagram shows the modular starting point: an ADC board, separately developed WINDOW/FFT/MEL/DCT/COMPARE laboratories, one controller, and distinct control versus data/address paths. The final design adds LOGMEL, UART DEBUG, runtime record/flush behavior, and revised board interfaces.

Table 4. Implemented data widths and memory boundaries.

Stage | Principal operation | Stored interface
ADC | SPI receive, average, center, preroll, VAD, zero pad | 16,384 x signed 12-bit
WINDOW | 512 signed samples x 8-bit Hann coefficient | 512 x signed 20-bit
FFT | 512-point fixed-point FFT and magnitude squared | 256 x unsigned 32-bit, bins 0-255
MEL | 32 overlapping filters over 256 power bins | 32 x unsigned 32-bit
LOGMEL | Piecewise interpolated log2 | 32 x unsigned 32-bit, 20 fraction bits
DCT | Non-DC DCT-II orders C1-C8 | 8 x signed 16-bit
COMP | Energy-aligned runtime enrollment or 30-reference SAD/L1 | Digit/result flags or one volatile 16-word reference-slot write
DEBUG | Marker-framed readout of all stage memories | 1,362 32-bit words per frame

frame_base(f) = 256 f, f = 0...62; frame = samples[frame_base ... frame_base + 511]
The 512-sample length with a 256-sample hop produces 63 frames and 50% overlap. Frame 62 begins at address 15,872 and ends exactly at 16,383. Reusing one arithmetic chain across those frames trades parallel throughput for resource efficiency and clarity. A push-button spoken-digit recognizer does not need to replicate 63 complete feature pipelines; it needs deterministic processing of every frame.

## 5 CTRL: Pipeline Orchestration

CTRL schedules the processing pipeline. Its ten-state main FSM is idle, ADC, WINDOW, FFT, MEL, LOGMEL, DCT, COMP, DEBUG, and done. One ADC acquisition occurs at the start of a run. WINDOW through COMP then repeat for all 63 frames, and DEBUG is inserted after COMP only when enabled. This organization ensures that the comparator receives the MEL energy and DCT vector from the same frame before the base address advances.
Every module transaction uses a three-phase start/ready contract. CTRL issues a one-clock start pulse, waits for ready to fall so that a stale idle-high level cannot be mistaken for completion, and then waits for ready to rise. A stage's pipeline depth can change without modifying CTRL, provided that its busy handshake remains unchanged.
The digit switches and trial buttons are also part of the control problem. Trial inputs pass through two flip-flops and a 500,000-clock debounce interval, approximately 5 ms at 100 MHz, and wrap through 0, 1, and 2. CTRL's UI selection registers may still update while idle or during ADC capture, but top_module copies mode, digit, and trial into dedicated run registers at the synchronized start edge. COMP uses those run registers, so later switch or button changes affect only the next run.

Figure 5. CTRL state progression, 63-frame loop, and optional DEBUG branch.
The diagram explains the key resource decision: acquisition occurs once, while one shared feature chain is reused across 63 overlapped frames. The optional debugger follows comparison and does not change the numerical route. Advancing only after a ready-low/ready-high transaction prevents one stage from reading a memory before the previous stage has finished writing it.

Table 5. Event encoding used by the CTRL numerical checker.

Checker event ID | Controller event
0 | ADC
1 | WINDOW
2 | FFT
3 | MEL
4 | LOGMEL
5 | DCT
6 | COMP
7 | DEBUG when enabled

Figure 6. CTRL XSim waveform across the complete repeated frame sequence. Behavioral simulation capture from the indexed controller testbench.
The dense start and ready activity is the expected repeated pipeline, not unexplained switching. The frame-address bus advances in 256-sample steps and reaches 15,872 before ready_out returns high. Each start pulse is followed by a modeled busy interval, showing that CTRL responds to completed transactions rather than emitting an uncontrolled sequence of stage pulses.

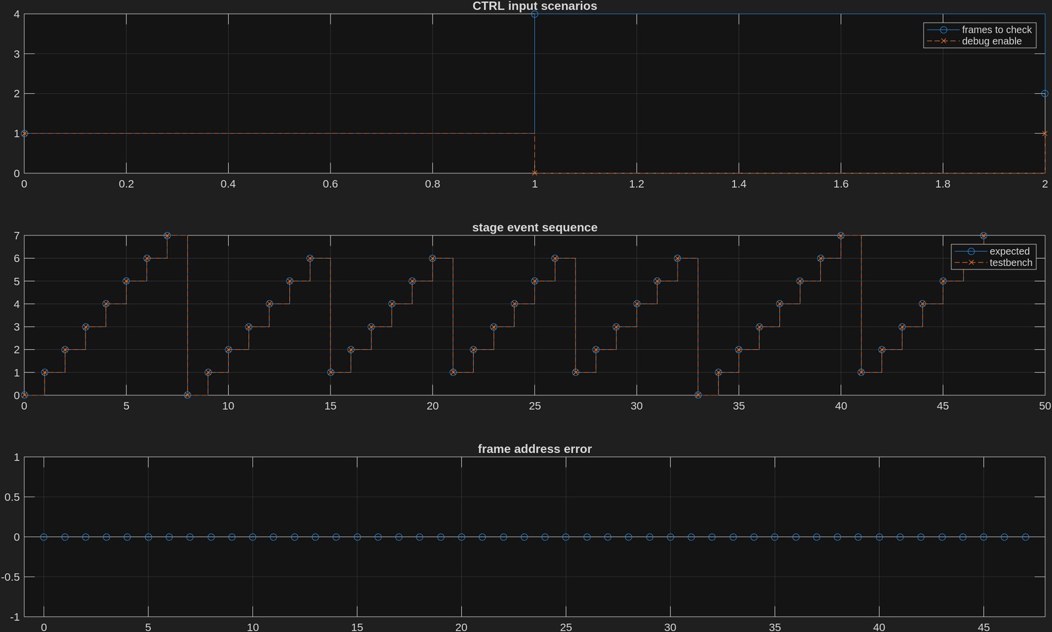
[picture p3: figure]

Figure 7. CTRL checker for stage order, debug branching, and frame addressing. Current integer checker export from the controller testbench outputs. The checker covers one frame with debugging enabled, four frames with it disabled, and two frames with it enabled. Expected and observed event IDs coincide in all 48 rows, and the frame-address error is zero. This checks both branches: DEBUG appears only after COMP when selected, and bypassing it does not disturb the remaining sequence.

The controller bench substitutes short ready pulses for the real processing blocks. It checks ordering, overlap, and debug branching; the following module chapters check the arithmetic and memory contents produced inside those transactions.

## 6 ADC: Acquisition, Averaging, and Voice Detection

ADC is more than a serial receiver: it accepts 12-bit words MSB first, averages 32 conversions, removes the unsigned midpoint, preserves 2,048 samples of preroll, detects the utterance boundaries, and guarantees a 16,384-word signed record for the downstream frame schedule. The state machine remains in the 100 MHz system domain and advances on a one-cycle enable every three clocks. The resulting controller tick is 33.333 MHz and SCLK is approximately 16.667 MHz because the receive and decode phases alternate the clock. I originally pursued a separate 36 MHz generated-clock solution. Although its behavioral simulation was convincing, implementation around the ADC and memory boundary became placement- and clock-domain-sensitive, and programmed-board behavior could diverge even during a forced-low serial-input diagnosis. I tried explicit synchronization and timing exceptions, IOB placement, KEEP and DONT_TOUCH attributes, and localized placement before choosing the single-domain enable.

The final tick is approximately 7.4%, conventionally rounded to about 8%, below 36 MHz. I accepted that difference because repeatable speech acquisition and comfortable implementation margin matter more than reproducing a nominal tick exactly. The ADC-rate decision is a documented timing tradeoff; it is distinct from FFT sample-order and address correctness, which are enforced as hard regression properties.
Including the 32 conversions and the acquisition-state overhead, one stored audio sample consumes 2,017 ADC-enable ticks. With the implemented 33.333 MHz enable, the effective stored-sample rate is approximately 16.526 kSa/s. A 512-sample frame therefore spans about 30.981 ms, the 256-sample hop about 15.491 ms, and a full 16,384-sample record about 0.991 s. The separate FFT unit test uses an exact synthetic rate of 16 kSa/s and is labeled accordingly. average[m] = floor(sum(raw[32m ... 32m+31]) / 32); signed_sample[m] = average[m] -2048
The centered value remains signed 13-bit; its lower 12 bits are stored as two's-complement audio, and a separate 13-bit magnitude feeds detection. Before speech begins, averaged samples continuously overwrite a 2,048-word circular buffer. Once that buffer has wrapped, the active onset logic sums three consecutive magnitude results and compares the sum with 1,000. The mapped n_on value is not used by the implementation, so onset is not described as a ten-sample test.
After onset, I reserve the first 2,048 locations of the main RAM and write new audio after that prefix. At completion I copy the circular preroll into addresses 0 through 2,047 in chronological order. This fillback protects the first consonant or attack that occurred before the threshold crossing. After at least 4,096 post-preroll samples, 1,024 consecutive magnitude results below 80 terminate active recording; the rest of the RAM is zero padded. If speech continues, capture reaches the end naturally. Both paths deliver exactly the record length expected by CTRL.

Table 6. ADC parameters and the design reason for each one.

Acquisition parameter | Active value | Reason
Raw words per stored sample | 32 | Suppress isolated converter noise before feature extraction
Effective stored-sample rate | Approximately 16.526 kSa/s | 2,017 ADC-enable ticks per averaged sample
Preroll | 2,048 samples | Recover the speech onset that precedes the threshold crossing
Onset decision | Three-result magnitude sum > 1,000 | Short level-sensitive trigger after preroll becomes valid
Minimum active record | 4,096 samples after preroll | Prevent an early quiet interval from ending the word
End decision | 1,024 consecutive magnitudes < 80 | Detect a sustained low-level tail
Main sample RAM | 16,384 x 12-bit | Provide the fixed 63-frame address space

Figure 8. ADC processing path from SPI conversion to the fixed recording RAM. Averaging, midpoint removal, preroll, and end detection are part of the architecture because faults at acquisition would contaminate every later feature. The fixed output length is equally important: it allows the controller to generate all frame addresses without negotiating a variable-sized buffer.

Figure 9. ADC XSim waveform showing the actual 12-bit serial transaction and storeddata interface.
Behavioral simulation capture from the indexed ADC testbench. The waveform shows active-low chip-select intervals, SCLK bursts, programmed MISO activity, ready/busy behavior, and decoded sample storage. It checks polarity, bit order, transaction boundaries, and the separation between clock movement and data sampling. The testbench uses shortened/bypassed detection parameters so that a regression can reach RAM readback quickly; it does not tune the microphone or exercise the full runtime VAD thresholds.

Module simulation checks deterministic SPI capture and storage. The later programmed-board ADC plots and retained spoken-input records show physical input passing through the development acquisition path.

## 7 WINDOW: Frame Extraction and Hann Multiplication

WINDOW extracts one 512-sample region of the ADC RAM and tapers its endpoints before the FFT. An FFT treats a finite frame as one period of a repeating waveform; if the two ends do not meet smoothly, the artificial discontinuity spreads energy across unrelated bins. The Hann taper reduces that leakage while retaining the frame's dominant speech structure.
y_f[n] = x[frame_base(f) + n] h_q[n], n = 0...511
The ADC sample is signed 12-bit and the quantized Hann coefficient is unsigned 8-bit. Their signed-by-unsigned multiplier produces a signed 20-bit product, which I retain without dividing by 255 in this stage. Carrying the coefficient scale forward avoids an unnecessary divider and keeps the convention identical in the FFT input and numerical checker.
The state sequence is idle, readr, four wait states, writer, write_ram, flush_last, and done. The waits align the synchronous ADC memory, coefficient ROM, and three-stage multiplier. The first writer pass primes the pipeline without writing; later passes commit addresses 0 through 510, and flush_last supplies the 512th write at address 511. A simulation-only contract checks that addresses 0 through 511 are written once and in order, and the final RAM vector matches all 512 Hann reference words. Because both Hann endpoints are zero, this test still cannot distinguish a stale or swapped final sample. A nonzero-endpoint diagnostic vector would close that specific gap. One multiplier is reused across the frame. At 100 MHz the operation takes about 3,585 clocks, or 35.85 microseconds, while CTRL depends only on the ready handshake. The 50% overlap is not hidden inside WINDOW. CTRL changes the frame base by 256 and WINDOW always performs the same local sweep from 0 through 511. This separation keeps the arithmetic simple, makes the memory latency visible, and allows exactly the same window datapath to serve every frame.
Table 7. WINDOW numeric interface and resource choice.
Item | Implemented choice | Consequence
Input | Signed 12-bit ADC sample | Preserves positive and negative centered audio
Coefficient | Unsigned 8-bit Hann ROM | Compact coefficient storage with a deterministic scale
Product | Signed 20-bit | Retains the complete multiply result for FFT input
Frame | 512 samples | Matches the configured FFT transform length
Resource use | One pipelined multiplier | Trades a short sequential latency for low duplication

Figure 10. WINDOW XSim waveform for a complete 512-sample transaction. Behavioral simulation capture from the indexed WINDOW testbench.
The local index, ADC address, coefficient address, and output write address traverse the frame while ready remains low. The Hann coefficient rises toward the center and falls at the far end, and the 20-bit product follows that envelope. The current regression adds an explicit 0-through-511 write-address assertion because the zero Hann endpoints alone could mask an endpoint association error.

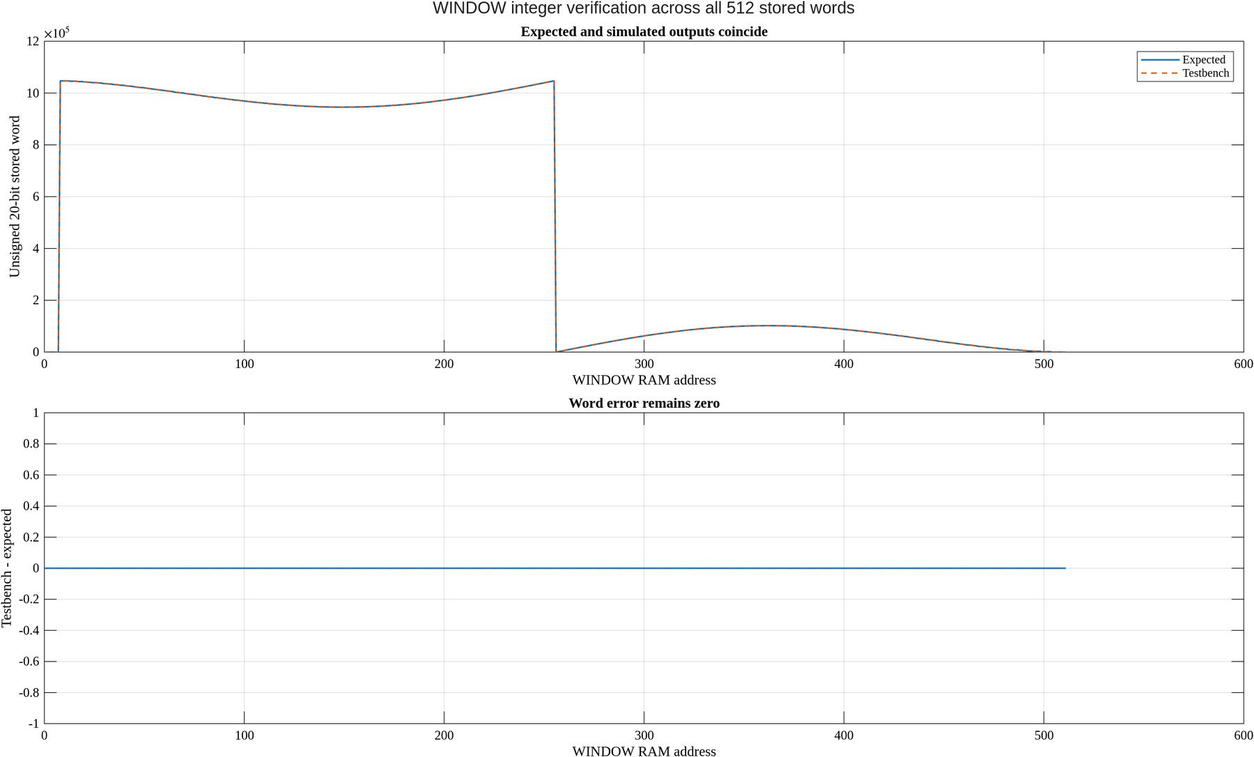
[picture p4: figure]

Figure 11. Bit-true WINDOW comparison across all 512 output words. Light-theme checker rendered from the retained WINDOW expected and testbench output tables. The checker independently multiplies the deterministic input by the retained 8-bit coefficient table. Expected and simulated curves coincide and the word-error trace remains zero. Where a viewer displays a negative 20-bit product as unsigned, it can appear close to 2^20; that is the ordinary two's-complement representation consumed correctly as signed data by FFT, not an arithmetic discontinuity.

This deterministic vector checks coefficient addressing, signed storage, multiplier latency,
and final RAM contents. The programmed-board window maps later in the report show the same operation applied across 63 frames from physical input.

## 8 FFT: AXI4-Stream Transform and Power Spectrum

FFT converts each 512-sample tapered frame into a one-sided power spectrum. This was my first AXI4-Stream IP integration. It was substantially simpler than my previous DMA experience because the recognizer needs only one configuration transaction, a real-valued input burst, tlast on the 512th accepted sample, valid complex outputs, and event monitoring. I left optional transport and transform features unused instead of carrying interface complexity that the application would never consume.
The AMD/Xilinx FFT core is configured as a 512-point fixed-point forward transform with a 20-bit input, 30-bit real and imaginary outputs, natural output order, unscaled arithmetic with truncation, Radix-2 Lite burst architecture, and a 100 MHz target [1], [2]. Each 20-bit WINDOW value is sign-extended into the real field of the 48-bit stream word and the imaginary field is set to zero. WINDOW RAM is synchronous, so the wrapper uses registered prefetch and holds each returned word until accepted. A one-word skid register captures an in-flight BRAM response when TREADY deasserts, ensuring samples 0 through 511 transfer exactly once, with TLAST on accepted sample 511.
P[k] = floor((Re{X[k]}^2 + Im{X[k]}^2) / 2^29), k = 0...255
Two signed 30-by-30 multipliers create 60-bit squares. I add them in 61 bits and store sum bits 60 downto 29 as an unsigned 32-bit magnitude-squared value. A square root would consume resources without changing which spectral region carries the most energy. Because the input is real, I retain bins 0 through 255: this includes DC and excludes the Nyquist bin at 256. The conjugate upper half contains no additional information for the MEL stage.
The magnitude multipliers have six registered stages. Together with the preceding real/imaginary wrapper latch, the power result for bin k is available when the output-event index reaches k+7. The wrapper therefore derives POWER_RESULT_DELAY as 6+1 and writes bins 0 through 255 to identically numbered RAM addresses. The wrapper states are idle, set_config, load_input, get_output, and done. Connected event pins expose missing or unexpected tlast and channel-halt conditions, while completion is controlled by counted valid outputs.

## 8.1 Correcting FFT bin-address alignment in a synthetic 16 kSa/s unit test

The FFT unit test uses an exact 16 kSa/s synthetic input, so a 1 kHz tone belongs at bin 32. The archived run placed the integer-reference peak at bin 32 but the DUT peak at RAM address 31. Although the magnitudes were close, the address was part of the wrapper contract and therefore incorrect. Cycle tracing showed that the old code waited eight output events even though the implemented path is one wrapper latch plus six multiplier stages. It dropped bin 0, stored bins 1 through 255 one address early, and duplicated bin 255 at the final address.
The first fix changed POWER_RESULT_DELAY to MULTIPLIER_LATENCY + 1, mapping bins 0 through 255 to addresses 0 through 255. A second review found that TREADY backpressure could still discard a pending synchronous WINDOW-RAM response, so I added registered prefetch and a one-word skid buffer. The wrapper now transfers samples 0 through 511 exactly once.
In the final synthetic 1 kHz test, the reference and RTL both peak at bin/address 32. The integer ideal is 4,882,812 and the DUT is 4,882,767; the maximum integer-ideal difference is 45, with one differing row out of 256. The RTL matches the AMD XFFT v9.1 bit-accurate C model in all 256 outputs.

Table 8. Corrected FFT addressing and numerical verification result.

FFT observation | Value | Engineering meaning
Integer ideal | Bin 32; 4,882,812 | Independent integer reference
RTL DUT | Address 32; 4,882,767 | Semantic FFT bin and RAM address agree
Integer-ideal comparison | Maximum difference 45; 1/256 rows differs | Passes the uniform 64-count bound
AMD XFFT v9.1 comparison | Exact 256/256; maximum difference 0 | Bit-accurate vendor-model parity
Retained-output gates | Peak bin/address checked; bins/addresses 0..255 retained | One-sided power-spectrum properties used by the project

Figure 12. Historical pre-fix FFT XSim waveform showing AXI input, transform latency, pipelined power calculation, and RAM writes. Behavioral simulation capture retained as defect-discovery context; it predates the synchronous-memory skid correction.
This view records the earlier transaction shape but is not used as current sample-order proof. Current retained-output evidence consists of the post-fix peak-address check, the independent integer comparison, and exact AMD bit-accurate agreement for all 256 stored one-sided power bins.

Figure 13. Synthetic 16 kSa/s FFT unit test: corrected 1 kHz reference bin 32 and DUT address 32.
Post-fix XSim output checked directly by the strengthened MATLAB verifier.
All three spectra peak at bin/address 32. RTL differs from the independent integer ideal by at most 45 counts in one row and matches the AMD bit-accurate model exactly in all 256 rows.

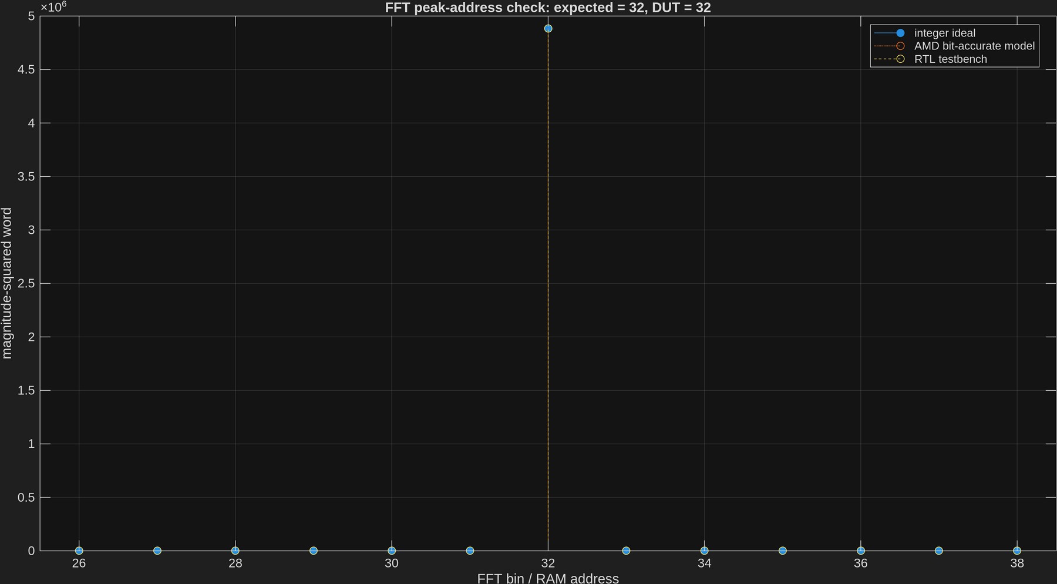
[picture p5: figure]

Figure 14. Synthetic 16 kSa/s unit-test close-up of exact bin-to-RAM alignment after the RTL correction.
Post-fix MATLAB address assertion rendered around bins 26 through 38. Both markers coincide at bin/address 32. This close-up makes the corrected interface property visible rather than relying on similar peak magnitudes or downstream MEL behavior.

The single-tone bench isolates AXI transfer, transform output, power arithmetic, and
storage. Address correctness is enforced locally; cross-frequency hardware captures and
real spoken-input maps then provide separate application-level spectral evidence.

## 9 MEL: Perceptual Filter-Bank Accumulation

MEL reduces the 256 correctly addressed linear-frequency power values to 32 overlapping band energies. The filter bank converts the linear-bin spectrum into a perceptual representation that emphasizes the broad spectral envelope used in speech features [4].

## 9.1 Addressed memories and fixed-point datapath

E_f[m] = sum(P_f[k] H[m,k], k=0...255); MEL_f[m] = (E_f[m] >> 16) mod 2^32, m=0...31

Figure 15. MEL addressed-memory and fixed-point arithmetic datapath. The same filter index m and bin index k acquire FFT power P[k] at address k and coefficient H[m,k] at address 256m+k. Their registered outputs feed one unsigned 32-by-16 multiplier and a 64-bit accumulator; bits 47 downto 16 are written as the 32-bit band result.

The coefficient memory contains 32 x 256 = 8,192 unsigned 16-bit words. Concatenating the five-bit filter number with the eight-bit FFT-bin number directly creates address 256m+k. One unsigned 32-by-16 multiplier produces a 48-bit product, which I accumulate in 64 bits. After the final bin, accumulator bits 47 downto 16 become the unsigned 32-bit band value, removing the coefficient's 16 fractional bits.
The implemented read schedule presents FFT[k] while the coefficient address presents 256m+k. The address is held until the top-level mux and synchronous FFT/coefficient memories have returned stable words; latency is handled by the counter, not by changing the requested mathematical index. This removes the former residual k+1 compensation that remained after the FFT RAM itself was corrected to store bin k at address k. One multiplier and accumulator are reused across all filters, requiring 8,192 multiply-accumulate iterations per frame and avoiding 32 duplicated filter datapaths.

## 9.2 Serialized address, accumulate, and write control

Figure 16. MEL nested-loop control for 256 bins and 32 filters. Start clears m and k. Each address/wait sequence acquires one synchronized FFT/coefficient pair; k=255 writes the completed band, and m=31 ends the transaction.

The states idle, start_filter, set_addr, load_mult, add, write_ram, write_wait, and done wait until the address-path and multiplier counters reach four. These waits are not arbitrary idle time. They prevent an address that looks correct in a waveform from being paired with data that still belongs to an earlier request.

## 9.3 Numerical and timing evidence

Figure 17. Retained MEL XSim waveform showing the repeated address, MAC, and 32-write control structure.
Development-stage behavioral capture retained from before the final FFT-bin/address identity correction.
The dense activity represents the 256-bin traversal repeated for every filter, and the state/latency structure remains applicable. This historical capture predates removal of the residual k+1 FFT request. Figure 15 shows the current address mapping, and Figure 18 checks numerically that H[m,k] consumes P[k].

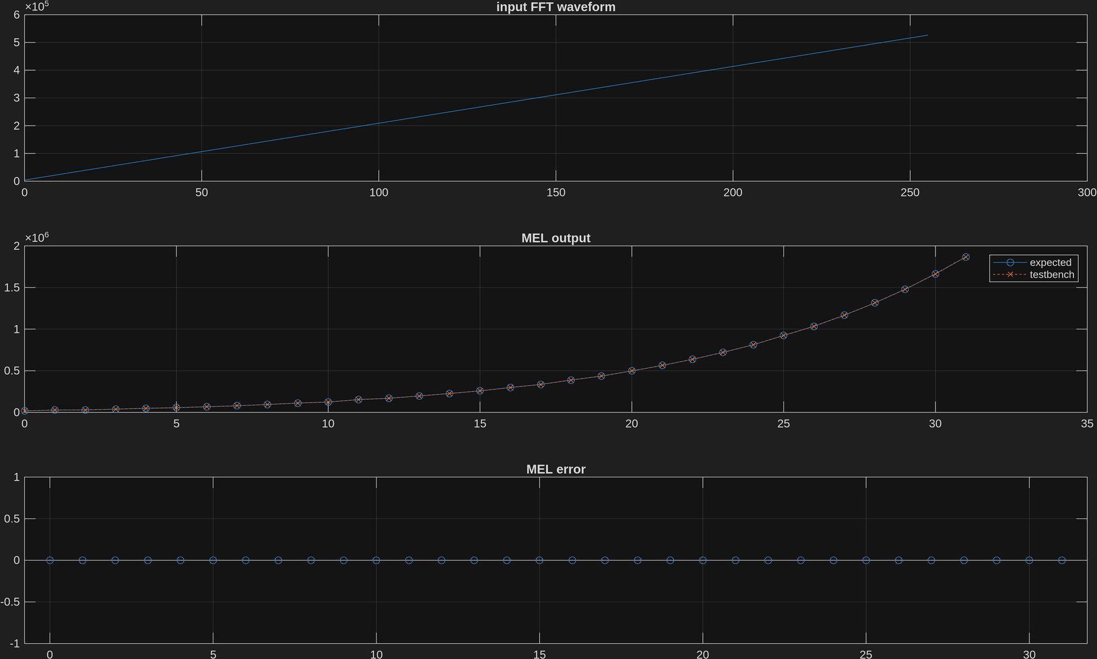
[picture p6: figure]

Figure 18. Exact 32-band MEL comparison after enforcing FFT-bin/address identity. Post-correction integer checker export from the MEL testbench output. The stimulus begins at 4,096 and increases by 2,048 at every FFT address, so pairing coefficient H[m,k] with any FFT word other than P[k] changes the result. Expected and simulated outputs overlap from band 0 through band 31 and the error is zero. This checks the ROM address, FFT address, multiplication, accumulation, scaling, and write path together. This ramp also checks the fixed-point filter bank and complements the later programmed-board frequency sweep.

## 10 LOGMEL: Piecewise Logarithmic Compression

Raw MEL energies can span several orders of magnitude. Feeding them directly to DCT would let a few large bands dominate the feature vector, so LOGMEL approximates log2 in fixed-point hardware. The logarithm compresses level while preserving the contour used by the later DCT [4], [5], without a floating-point unit or long iterative algorithm.

## 10.1 Binary normalization and interpolation datapath

x' = max(x,1); e = floor(log2(x')); L = (e << 20) + base[a] + ((slope[a] residual) >> 8)

Figure 19. LOGMEL binary normalization, ROM lookup, and interpolation datapath. The leading-one search converts the logarithm into an exponent plus normalized mantissa. Bits 30 downto 19 form the 12-bit ROM address, bits 18 downto 11 form the interpolation residual, and the packed base/slope word drives a 12-by-8 multiply. The exponent and interpolated fraction share one unsigned 32-bit word with scale 2^-20.

After clamping zero to one, I find the highest set bit e and shift the word until its leading one occupies bit 31. Normalized bits 30 downto 19 select one of 4,096 ROM segments, and bits 18 downto 11 form an eight-bit interpolation residual. Each 32-bit ROM word packs a 20-bit base and 12-bit slope. A 12-by-8 multiplier produces the correction, and adding the exponent in a 2^20 scale yields the 32-bit result. Zero and unity consequently map deterministically to zero.

## 10.2 Per-band address, wait, and write control

Figure 20. LOGMEL 32-band sequential control and synchronous-memory waits. Start initializes bin once. Each iteration requests MEL[bin], waits four counts, forms the ROM address, waits two counts for the ROM and four for the multiplier, and writes LOGMEL[bin]. bin=31 raises ready; otherwise bin increments.

The sequential states are idle, set_mel_addr, wait_mel, set_rom_addr, wait_rom, load_mult, wait_mult, write_ram, write_wait, and done. For each of 32 bands I allow four counts for the MEL memory, two for the logarithm ROM, and four for the multiplier. One small ROM/multiplier path is reused for every band, giving a fixed and observable order from address 0 through 31.

## 10.3 Boundary behavior and numerical evidence

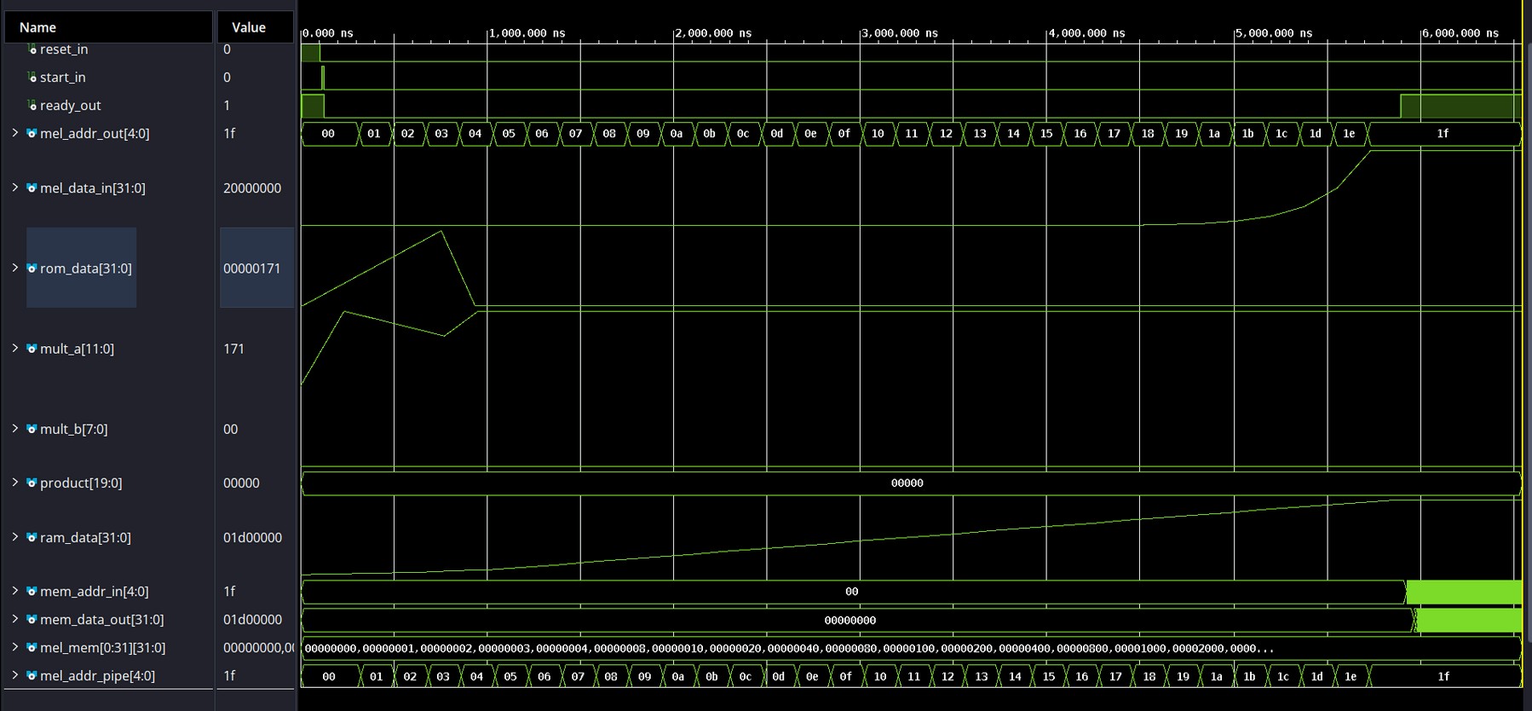
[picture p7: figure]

Figure 21. LOGMEL XSim waveform showing MEL reads, normalization, ROM interpolation, and output writes. Behavioral simulation capture from the indexed LOGMEL testbench.
The MEL address steps across all 32 entries while the exponent, ROM data, slope/residual product, and final word change after their scheduled delays. ready remains low until the last write. The timing view shows an explicit piecewise datapath with controlled synchronous latency.

Figure 22. Boundary-focused LOGMEL comparison across zero, powers of two, and neighboring values.
Current integer checker export from the LOGMEL testbench output. The 32 inputs include zero, unity, powers of two, and values immediately above or below exponent boundaries. Expected and simulated words coincide and the error is zero. Exact powers confirm the 20-fraction-bit scale directly, while adjacent values exercise the ROM address and interpolation residual. The visible compression of the high-dynamic-range input is the intended feature, not a loss of the spectral contour.

The checker covers the implemented approximation and boundary handling, not equivalence to an unrestricted floating-point logarithm. Reference features use the same quantization, so COMP compares like with like.

## 11 DCT: Eight-Coefficient Feature Compression

DCT converts each 32-value log-MEL contour into eight signed coefficients [4], [5]. The cosine ROM implements non-DC DCT-II orders C1 through C8; hardware index 0 represents C1, not C0. MEL energy is retained separately for speech-onset selection, while the non-DC coefficients describe spectral shape for template distance.
A_q = sum(L[m] Q[q,m], m=0...31); C_q = ASR(A_q + 2^29 if A_q>=0 else A_q - 2^29, 30) Each LOGMEL word is unsigned 32-bit and each cosine coefficient is signed 16-bit, approximately Q1.15. Their product is signed 48-bit and the 32 terms accumulate in signed 64-bit precision. The RTL adds 2^29 for a non-negative accumulator and subtracts 2^29 for a negative accumulator before the arithmetic right shift by 30, then retains signed 16 bits. This is a deterministic sign-dependent quantization convention reproduced by the checker; the negative side is biased away from zero, so it is not symmetric round-to-nearest.
The cosine address is 32(q-1)+m. The LOGMEL request is issued as (m+31) modulo 32 to compensate the registered upstream read path; this is a memory-scheduling alignment, not a rotation of the reported feature vector. The states idle, set_addr, load_mult, add, write_ram, write_wait, next_dct, and done perform 32 multiply-accumulate iterations per coefficient and repeat for all eight orders using one datapath.

Figure 23. DCT XSim waveform across eight 32-sample cosine sweeps. Behavioral simulation capture from the indexed DCT testbench.
The LOGMEL input contour is revisited for every transform order while the cosine sequence oscillates progressively faster. Product and accumulator values change polarity, and the output RAM contains both positive and negative coefficients. The repeated pattern explains how one arithmetic path produces all eight features before ready returns high.

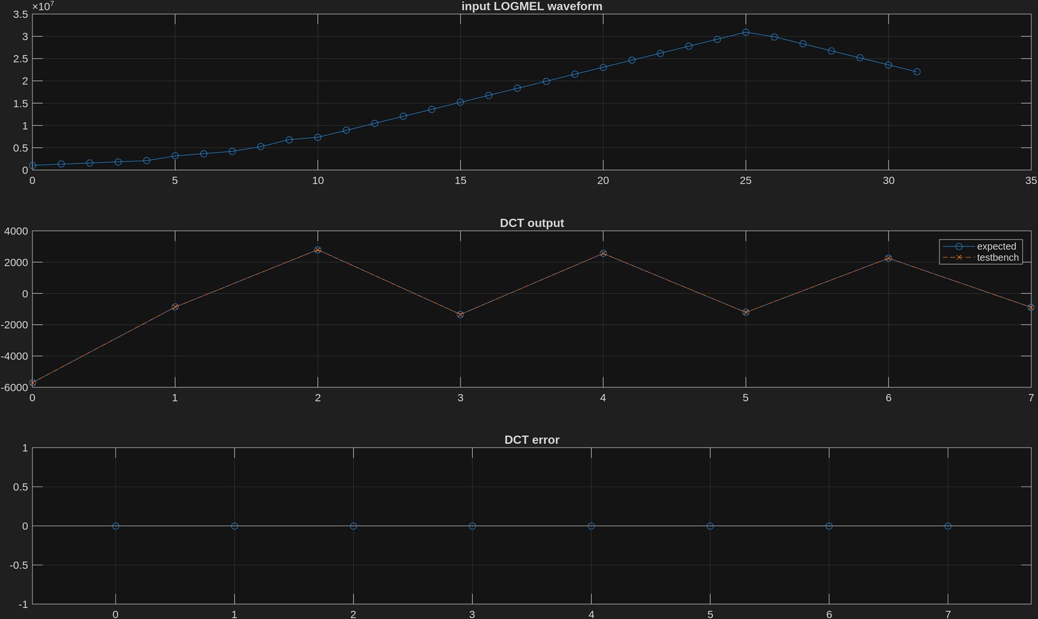
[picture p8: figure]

Figure 24. Exact fixed-point DCT comparison for the eight C1-to-C8 outputs. Current integer checker export from the DCT testbench output. The tested contour produces [-5702, -873, 2794, -1342, 2555, -1211, 2250, -891]. Expected and simulated traces overlap at every coefficient and the error is zero. Alternating positive and negative results simultaneously exercise cosine addressing, signed multiplication, wide accumulation, sign-dependent rounding, 16-bit conversion, and RAM ordering.

The deterministic contour checks the complete fixed-point DCT datapath. Spoken-input and programmed-board DCT maps later show the same eight-word interface populated by acquired signals.

## 12 COMP: Runtime Enrollment, Active-Window Selection, and Template Matching

COMP handles both runtime enrollment and nearest-template classification. In record mode, one processed utterance is reduced to an energy-aligned interval of sixteen 128-bit DCT feature words and written into the selected digit/trial slot. This is the main adaptation path because it replaces a startup example with a speaker-specific template without resynthesis. In compare mode, the same writable RAM supplies the templates for SAD/L1 distance.

## 12.1 Frame feature acquisition and binary packing

COMP receives one completed feature frame at a time. It addresses all 32 MEL bands and accumulates them into one unsigned 64-bit energy value. It then addresses the eight DCT outputs and packs the signed 16-bit C1-through-C8 words into one 128-bit frame. A 64-word utterance RAM stores the 63 captured feature frames.
energy[f] = sum(MEL_f[m], m=0...31)
U[f][127:0] = C1[15:0] | C2[15:0] | ... | C8[15:0]

Figure 25. COMP per-frame MEL-energy accumulation and DCT feature packing. Thirty-two addressed unsigned MEL words form one 64-bit frame-energy sum. Eight signed 16-bit DCT words are packed in C1-through-C8 order into one 128-bit utterance-RAM word.

The two serialized reads preserve different information: energy provides speech timing while the signed DCT word provides spectral shape. The resulting energy[f] and U[f] entries share the same frame number, so later enrollment and comparison use the timing decision without changing the feature-word layout.

## 12.2 Active-window threshold and start-address control

threshold = floor(max(energy) / 8); active_start = 0 if no crossing, else min(first f with energy[f] > threshold, 47)

Figure 26. COMP final-frame activity threshold scan and legal 16-frame start selection. After frame 62, threshold=max_energy>>3 implements division by eight. The scan selects the first energy strictly above threshold, retains zero when no crossing exists, and clamps a crossing after frame 47 to the final legal 16-frame start. Record and compare modes therefore receive the same active_start value.

The activity threshold is one eighth of the maximum frame energy. The first frame strictly above that threshold selects the speech start, and any later value is ignored. If the first crossing occurs after the last complete 16-frame interval, the start is clamped to 47; if no frame crosses the threshold, the initialized start value remains zero. Enrollment and comparison therefore consume the same U[active_start] through U[active_start+15] interval.

## 12.3 Writable reference-RAM address map and configuration-time seed

The implemented reference store is a writable 512-by-128 simple dual-port RAM. FPGA configuration initializes addresses 0 through 479 with 30 default templates: ten digits, three trials per digit, and 16 frames per trial. Addresses 480 through 511 are zero-filled spare locations. The initialization image is included for immediate comparison, deterministic simulation, and convenient demonstration; it does not turn the store into a ROM and it is not a substitute for runtime enrollment.
reference = 3d+t; slot_base = 16(3d+t) = 48d+16t; address = slot_base+i

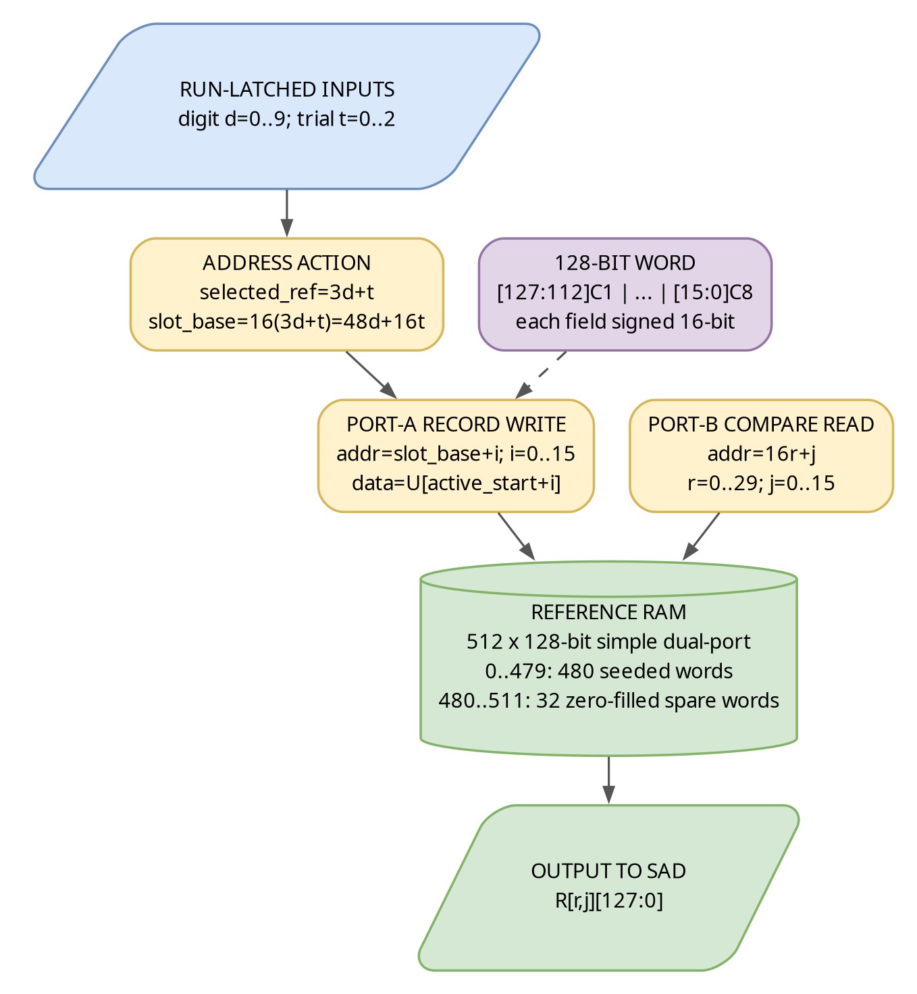
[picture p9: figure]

Figure 27. Writable COMP reference-RAM dimensions, address mapping, and 128-bit word format.
The 512-by-128 simple dual-port RAM holds 30 populated 16-frame slots at addresses 0 through 479 and leaves 32 spare zero-filled words. Record address 16(3d+t)+i and compare address 16r+j use the same C1-through-C8 word layout.

The COE was generated from saved development recordings and gives the FPGA a repeatable template set at configuration. Runtime recording remains the normal adaptation path and overwrites whichever digit/trial slot the user selects. Because the saved recordings predate the final FFT/MEL address corrections, the seed is not used as a current live-accuracy result.

## 12.4 Runtime speaker-specific enrollment

At the synchronized top-level start edge, record/compare mode, selected digit, and selected trial are copied into run registers and remain stable for the full acquisition and 63-frame feature sequence. In record mode, the final active_start drives a sixteen-word copy from utterance RAM into the selected reference slot. Every recorded word uses the same C1-through-C8 packing as the COE, so comparison does not need a separate format for default and user-enrolled templates.
R[3d+t, i] <- U[active_start+i], i=0...15

Figure 28. Runtime enrollment state flow and exact utterance-to-reference address translation.
One shared BRAM read path retrieves U[active_start+i], and one reference-RAM write pulse stores that 128-bit word at 16(3d+t)+i. The i=15 decision terminates after exactly sixteen writes, asserts record_out and valid_out, returns the enrolled digit, and makes COMP ready for the next transaction. No COE regeneration or bitstream rebuild occurs during enrollment.

The update is volatile but persists through an ordinary control reset because that reset does not rewrite BRAM. Reconfiguring the FPGA restores the COE-seeded startup collection. This behavior supports two useful workflows: immediate comparison using the repeatable default set, or speaker adaptation by replacing any selected digit/trial slot at runtime.

## 12.5 Reference-memory lifecycle and maintenance ownership

Figure 29. COMP reference-memory initialization, runtime ownership, reset, flush, and reconfiguration lifecycle. The COE seeds the RAM only at FPGA configuration. Runtime enrollment overwrites one selected slot, control reset preserves those words, reconfiguration restores the seed, and a gated maintenance flush writes zero to all 512 addresses. The current design has no validity bitmap, so the lifecycle explicitly states that a complete flush requires all 30 slots to be repopulated or the FPGA to be reconfigured before meaningful comparison.

Runtime recording and flush share reference-RAM port A through an explicit owner selection rather than bitwise-OR address composition. top_module first gates BTND with the complete CTRL ready state, and COMP then synchronizes the request and admits it only while its own FSM is idle at the run boundary. A press during ADC, feature extraction, comparison, or sixteen-word enrollment therefore cannot steal the reference-RAM write port. Flush writes zero to all 512 locations and then asserts flush_done.
Flush means erase, not restore defaults. The current classifier has no per-slot validity bitmap, so zero-filled locations still participate in SAD. Meaningful comparison after a complete flush consequently requires reconfiguration to reload the COE or repopulation of all 30 reference slots. Runtime overwrite itself does not require flushing: any chosen digit/trial slot can be replaced directly.

## 12.6 Signed-coefficient SAD/L1 datapath

D(r,w) = sum(abs(U[w+j,k] - R[r,j,k]), j=0...15, k=0...7)
Starting at received frame 15, each newly available 16-frame window is compared with all 30 references. Utterance address w+j and reference address 16r+j acquire the two 128-bit frame words. For each of their eight coefficients, both signed 16-bit values are extended to 17 bits before subtraction; the 17-bit magnitude is accumulated into unsigned 64-bit pair, reference, and best-distance registers.

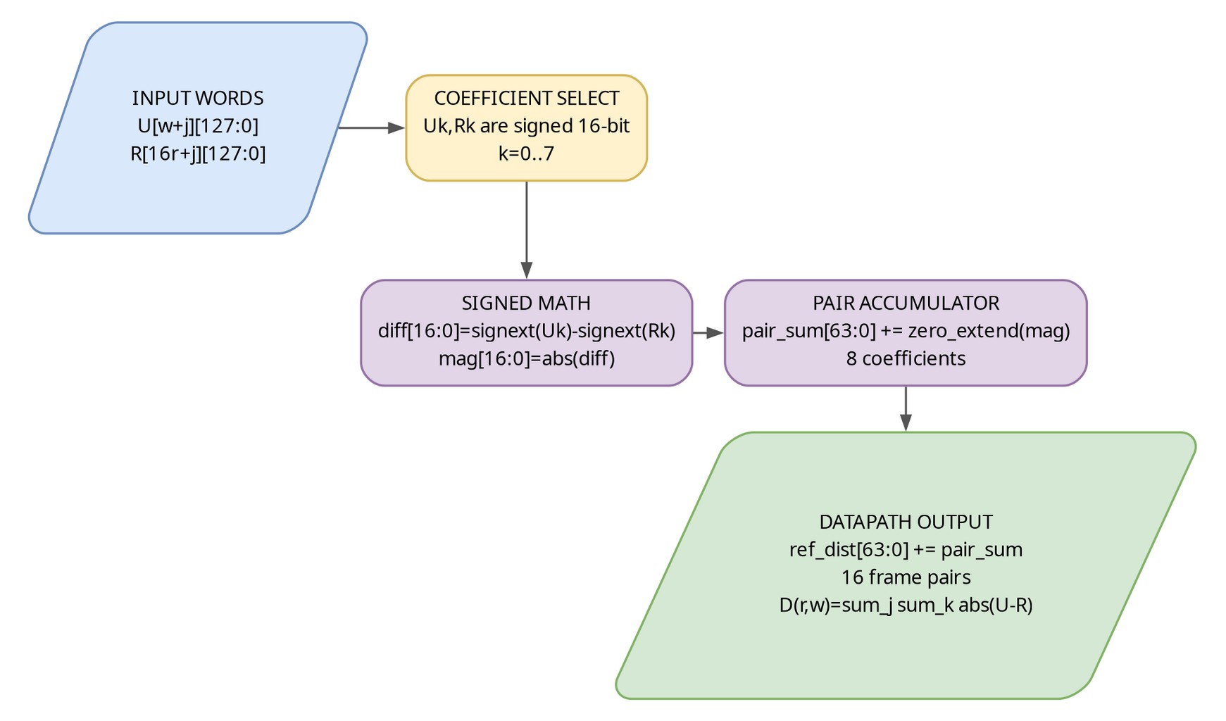
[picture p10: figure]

Figure 30. COMP addressed signed-coefficient absolute-difference datapath. Utterance address w+j and reference address 16r+j acquire two packed 128-bit words. Coefficient field k from each word is sign-extended to 17 bits before subtraction; the magnitude accumulates across eight fields and then sixteen frame pairs in 64-bit registers.

## 12.7 Nested comparison control and final digit selection

Figure 31. COMP coefficient, frame-pair, and reference-loop control for one window. k=7 closes one 128-bit word pair, j=15 closes one reference distance, and r=29 yields the winning reference for window w.

The workload is 48 window starts x 30 references x 16 frames x 8 coefficients = 184,320 absolute differences for one utterance. Reusing one comparison path avoids 30 parallel engines. Registered-memory wait states ensure that the address equations shown in the diagram acquire the intended utterance and reference words before arithmetic begins.

Figure 32. COMP per-window winner storage and final activity-aligned digit selection. Frames 15 through 61 store a winner and return ready for the next feature frame. Frame 62 uses active_start to select the stored window digit and raises valid_out.

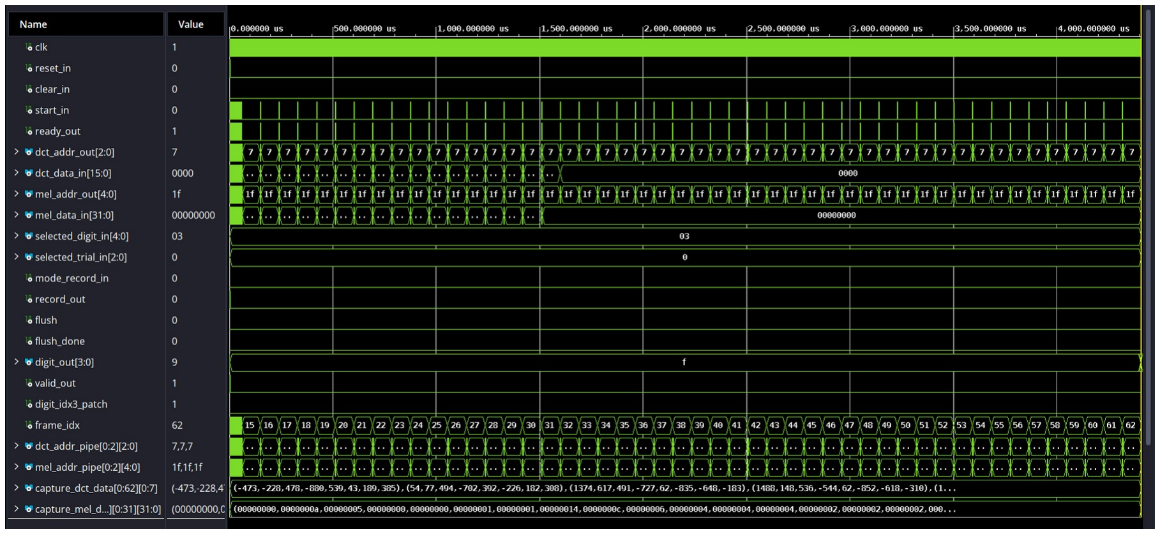
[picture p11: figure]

Figure 33. COMP XSim waveform across the 63-frame compare-mode sequence. Behavioral simulation capture from the indexed COMP testbench. The waveform shows repeated frame transactions, MEL and DCT memory reads, window/reference progress, compare mode held active, and the final valid digit 9. The selected digit/trial input is irrelevant in compare mode, so the result is produced by the stored SAD calculation rather than copied from a label port.

Figure 34. COMP checker showing energy onset, best reference by window, and the digit-9 result.
Current integer checker export from the COMP testbench output. The maximum MEL energy is 543,737, making the integer threshold 67,967. The first crossing is frame 7 with energy 98,039. At that start, reference 27 has the winning SAD of 27,338 and maps to digit 9. Other starts may prefer other references; the final result follows the stated energy-aligned rule rather than a fixed or globally forced digit.

## 12.8 Focused record-and-recall verification

Table 9. Focused COMP record-and-recall simulation result.

Focused COMP transaction | Observed result | Property exercised
Compare the retained capture against the configuration seed | valid=1; digit=9; record=0 | Baseline compare path and seeded-RAM read
Enroll the same active 16-frame window into digit 2, trial 1 | valid=1; digit=2; record=1 | Functional enrollment completion for reference 7, mapped to addresses 112..127
Clear only run state and compare the unchanged capture again | valid=1; digit=2; record=0 | Runtime word persistence and subsequent readback

For digit 2/trial 1, selected_ref=3(2)+1=7 and the implemented slot formula maps its sixteen words to addresses 112 through 127. The two-line test output is an assertion-backed functional summary of enrollment completion and later recall; it is not an address-by-address dump of all sixteen write cycles.
The COMP bench first classifies the saved sequence as digit 9, records its selected 16-frame window into digit 2/trial 1, and then classifies the same sequence as digit 2. This checks a write followed by readback at the COMP boundary without the impractical one-second ADC stimulus. It does not exercise microphone acquisition or measure live recognition accuracy. Likewise, a stationary tone that returns digit 3 checks completed comparison and result serialization, not recognition of a spoken label.

## 13 DEBUG: UART Observability

DEBUG acts as an internal instrument for the programmed FPGA. When enabled after COMP, it temporarily owns the read addresses of the ADC, WINDOW, FFT, MEL, LOGMEL, and DCT memories and serializes a complete frame. This makes it possible to locate the first stage with an unexpected value instead of diagnosing the recognizer from one output digit.
The packet is self-delimiting. A frame marker is followed by the frame base address and one packed COMP-status word. Markers AABBCC01 through AABBCC06 then introduce 512 ADC samples, 512 WINDOW samples, 256 FFT values, 32 MEL values, 32 LOGMEL values, and eight DCT coefficients. AA5503CC terminates the packet. Including the frame/status words, seven section markers, and end marker gives 1,362 32-bit words.

Figure 35. DEBUG UART packet order and section lengths. The marker structure turns one serial byte stream into a deterministic snapshot of all major stage memories. The same address convention is preserved from the FPGA through the PC plot, so I can compare simulation, checker output, and programmed-board data at a defined module boundary rather than guessing from a final digit alone.

Table 10. DEBUG packet fields and their interpretation.

Packet item | 32-bit marker or length | Meaning
Frame | AABBCC00 + address + COMP info | Identifies the 256-sample frame base and current mode/result flags
ADC | AABBCC01 + 512 words | Signed 12-bit source samples, extended into 32-bit transport words
WINDOW | AABBCC02 + 512 words | Signed 20-bit Hann products
FFT | AABBCC03 + 256 words | Unsigned 32-bit one-sided power values
MEL | AABBCC04 + 32 words | Unsigned perceptual-band energies
LOGMEL | AABBCC05 + 32 words | Unsigned fixed-point log2 values
DCT | AABBCC06 + 8 words | Signed 16-bit C1-to-C8 coefficients
End | AA5503CC | Closes the frame packet

Each word is sent most-significant byte first; each UART byte follows the ordinary leastsignificant-bit-first 8N1 convention. Four bytes require 40 serial bits, so 1,362 words at 1 Mbaud require 54.48 ms per frame. Exporting all 63 frames takes approximately 3.43 seconds. That cost exists only with debugging enabled. In normal operation CTRL bypasses DEBUG and the recognition path is not burdened by full-memory serialization.

Figure 36. DEBUG packet comparison for the complete 1,362-word UART sequence. Current checker export from the DEBUG testbench output. The test stimulus deliberately uses the synthetic frame-address field 507 and a COMP status encoding for digit 9 so that serialization is checked with nontrivial values. Address 507 is not presented as an operational 256-aligned frame base. The marker/status words and following data overlap the expected trace, and the error remains zero through word 1,362. A raw hexadecimal-to-decimal comparison also gives 1,362 matches and zero mismatches, checking packet markers, section order, word extension, and complete-length serialization.

The DEBUG bench checks digital packet construction. The programmed-board sections later show a PC parser recovering stage arrays and a final result from the physical UART link.

## 14 Seven-Segment Display and Top-Level Integration

The display translates mode and result state into a compact user-facing view. In record mode I display r d digit trial. In compare mode I display C d d result after COMP asserts valid; before that event the result position remains zero. This makes it possible to conduct a basic board experiment without keeping the UART receiver connected.
The four anodes and seven segment lines are active low. Counter bits 16 downto 15 select one display position, so each phase lasts 327.68 microseconds at 100 MHz and a complete four-digit scan lasts 1.31072 ms. The decoder covers digits 0 through 9 and the letters r, C, and d. That refresh is fast enough for a steady visual result while requiring only one shared segment decoder.

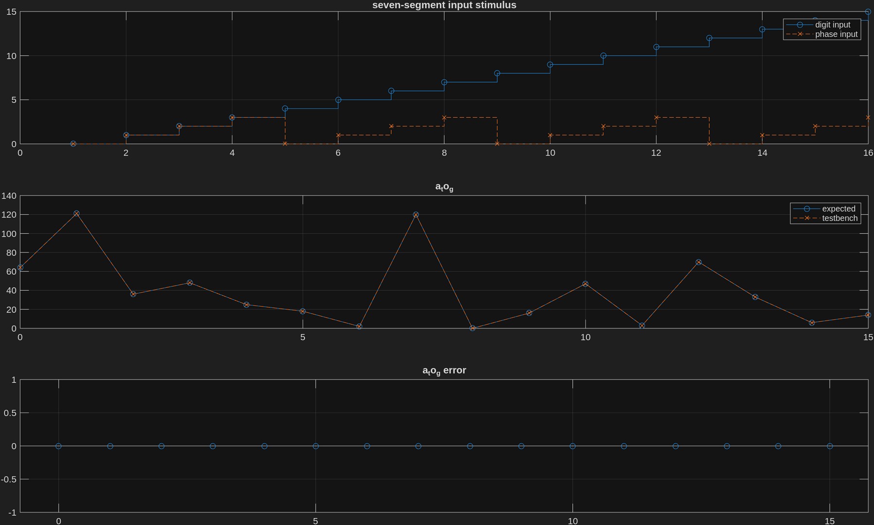
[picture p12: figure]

Figure 37. Seven-segment decoder comparison across numerical and letter symbols. Current checker export from the display testbench output. The stimulus traverses the supported digit/symbol and multiplexing-phase combinations. Expected and simulated active-low segment words overlap in all 16 cases and the error remains zero. This validates the symbol table and polarity used by the top-level display path, not merely one photographed result.

The top-level integration connects the stage memories, start/ready signals, controls, display, LEDs, ADC pins, and UART. A compact smoke test verifies simple integrated observables such as a switch reflected on a PMOD path and debug enable reflected on an LED. I do not treat that limited smoke test as proof of the complete recognizer; the controller, module, packet, and programmed-board evidence supply that coverage.
A full ADC-to-COMP behavioral run is intentionally absent. The implemented acquisition alone represents about 0.991 s of sampled time and requires many more simulator clock events than the safe module suite, so tb_ADC is excluded from the default regression. The focused COMP enrollment/recall bench bypasses that long acquisition while preserving the writablereference transaction under test.

Table 11. Role and limit of the top-level integration checks.

Integration layer | What it checks | What it does not replace
Display checker | Active-low symbols and scan selection | Recognition arithmetic
Top-level smoke | Basic net connectivity and selected observables | Full ADC-to-COMP operation
CTRL checker | Ordered stage launches and frame addresses | Per-stage numeric correctness
Programmed-board UART | Integrated memories and serialized result | A multi-speaker recognition study

## 15 Verification Methodology and Module Results

Verification was developed alongside the RTL. Each major stage uses a VHDL testbench, a saved text interface, and a MATLAB checker. The testbench exercises the handshakes and synchronous-memory timing, the text output provides a stable boundary, and the checker recomputes or interprets the fixed-point result. This keeps the hardware timing context while making long memory outputs practical to inspect.

Figure 38. Text-first XSim-to-MATLAB verification workflow. The same repeatable interface is used throughout the project: a deterministic stimulus enters the DUT, XSim writes addressable results, and an independent numerical routine reports both the expected/actual traces and their error. Raw waveforms remain beside the checker plots because agreement without timing context would not expose a misaligned BRAM or handshake.

Table 12. Module-level verification results and why each one matters.

Module | Direct retained result | Meaning in the system
ADC | Serial transactions and six explicit RAM readback values agree | Acquisition words reach deterministic storage
CTRL | 48/48 expected event rows; zero frame-address error | Stage order, overlap, and debug branches are correct
WINDOW | 512/512 words agree; write addresses 0..511 asserted | Final RAM contents and write-address count/order are checked
FFT | Peak bin/address 32; integer-ideal max error 45; AMD parity 256/256 | Peak address and all 256 retained one-sided power words are checked against independent references
MEL | 32/32 words agree | All filter/coefficient/address paths are exercised
LOGMEL | 32/32 displayed differences are zero | Manual diagnostic review covers exponent, ROM, interpolation, and zero clamp
DCT | 8/8 displayed differences are zero | Manual diagnostic review covers C1-C8 addressing, accumulation, and quantization
COMP | Energy start 7, reference 27, digit 9, SAD 27,338 | The compare result follows the implemented onset rule
DEBUG | 1,362/1,362 UART words agree | Every packet section is serialized in the intended order
Display | 16/16 tested symbol/phase words agree | Active-low result presentation is correct

The automated checks and the diagnostic plots are distinguished deliberately. FFT, MEL, WINDOW, CTRL, COMP, DEBUG, and display checks contain assertion or mismatch gates at their stated boundaries. The retained LOGMEL and DCT figures were manually reviewed against generated expected vectors and show zero displayed differences; their current MATLAB scripts are diagnostic comparisons rather than automated numerical pass gates. An XSim PASS for those benches denotes bounded simulation completion, not an independent numerical verdict.

## 16 Programmed-Board Debugger Demonstration

I exercised the programmed FPGA with stationary inputs at 100 Hz, 500 Hz, 1 kHz, 2 kHz, and 4 kHz and exported the internal stage memories over the DEBUG channel. A tone is not a spoken digit, but it is a strong integration probe because its frequency is known and its expected movement through FFT and MEL is easy to interpret. The 1 kHz sequence below is shown without skipping a component: ADC, Hann overlap-add view, WINDOW frame map, FFT, MEL, LOGMEL, and DCT.
These 3 June captures predate the later FFT and MEL address-identity corrections [7]. They are historical evidence of frequency-responsive end-to-end memory population; current P[k]-to-H[m,k] correctness comes from the post-correction module regressions.

Figure 39. Programmed-board 1 kHz experiment: ADC capture. UART capture from the programmed Basys 3, 3 June 2026. The complete 16,384-sample record contains continuous centered tone activity. At page scale many cycles merge into a dense band; the relevant result is sustained signed acquisition, RAM storage, and successful UART reconstruction rather than a precision distortion measurement.

Figure 40. Programmed-board 1 kHz experiment: Hann-window overlap-add reconstruction.
UART capture from the programmed Basys 3, 3 June 2026. This view overlays/reconstructs all 63 tapered frames, so it should not be read as one isolated coefficient curve. It shows continuous 256-sample-hop coverage and the intended overlap between adjacent frames.

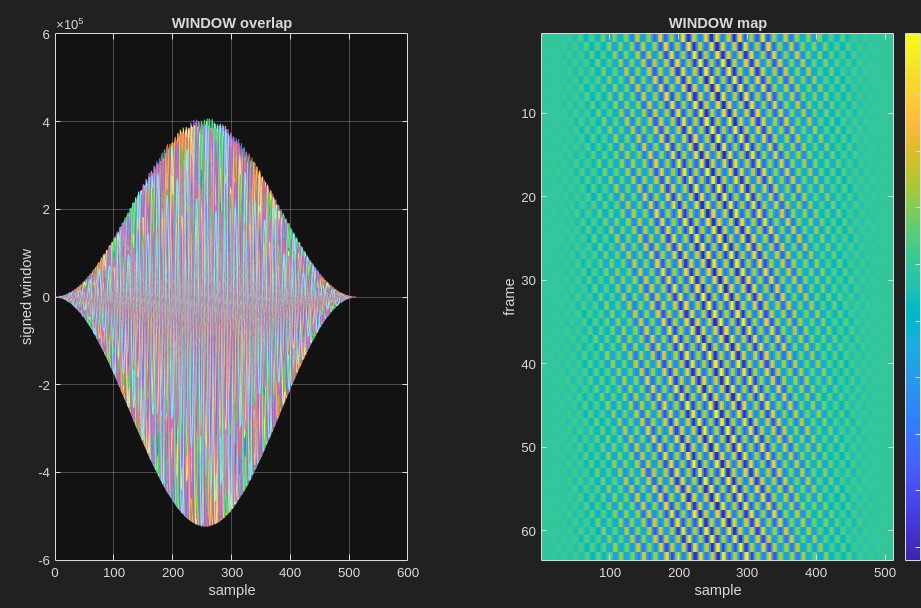
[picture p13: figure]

Figure 41. Programmed-board 1 kHz experiment: WINDOW output across all frames. UART capture from the programmed Basys 3, 3 June 2026. The frame-domain plot and map show repeated tapered 512-sample records rather than one unexplained trace. Stable structure across frames confirms that frame-base progression, sample reads, coefficient application, and UART frame assembly remain coherent on programmed hardware.

Figure 42. Programmed-board 1 kHz experiment: FFT power output. UART capture from the programmed Basys 3, 3 June 2026.
The spectrum remains concentrated near the applied-tone region across the frame sequence. This historical capture shows frequency localization after physical acquisition through the development AXI/power pipeline.

Figure 43. Programmed-board 1 kHz experiment: MEL filter-bank output. UART capture from the programmed Basys 3, 3 June 2026. MEL gathers the development-bitstream FFT values into overlapping perceptual bands. This historical application-level behavior is not used as evidence for the later corrected bin/address contract.

Figure 44. Programmed-board 1 kHz experiment: LOGMEL output. UART capture from the programmed Basys 3, 3 June 2026.
The same band contour remains visible after logarithmic compression while the dynamic range is reduced. This is the intended preparation for DCT, not a separate classification result.

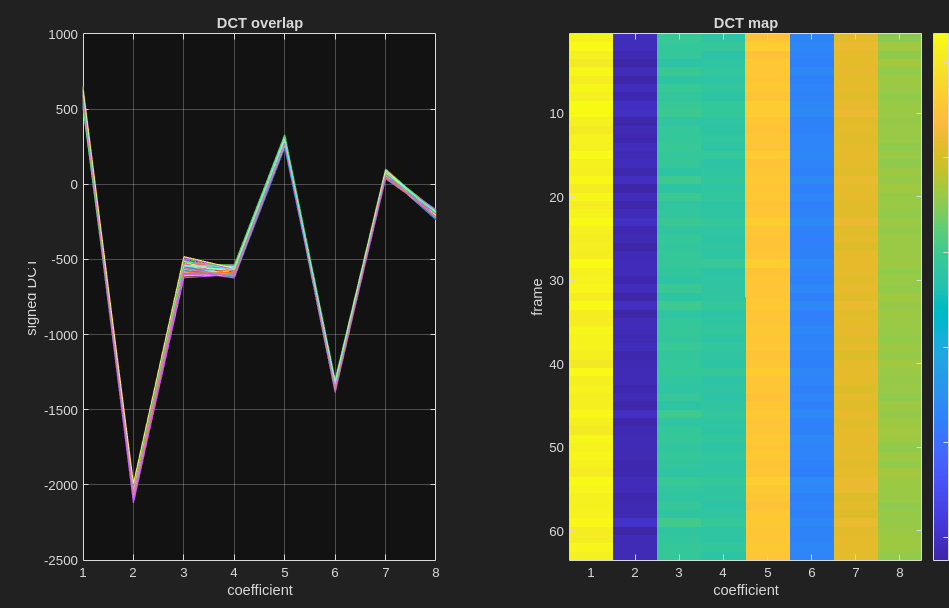
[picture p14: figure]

Figure 45. Programmed-board 1 kHz experiment: DCT C1-to-C8 output.
UART capture from the programmed Basys 3, 3 June 2026; a blank left margin was added for label readability without altering the captured pixels. The final eight-coefficient pattern remains stable across the stationary capture. This shows that data progressed coherently through every fixed-point stage and reached the exact compact interface consumed by COMP.

## 16.1 Complete frame progression and serialized compare result

A retained 4 kHz capture contains 63 packets with frame bases 0, 256, 512, and so on through 15,872. Every packet is in compare mode. At the physical acquisition rate, 4 kHz corresponds to fractional FFT bin 123.924, whose nearest semantic bin is 124. The retained development bitstream stores the maximum at RAM address 123 for all 63 frames, consistent with its legacy one-address shift. The MATLAB plot labels MEL hardware index 31 as band 32. At the final frame COMP valid rises and digit code 3 is serialized. This checks execution of the comparison and result path, not recognition of a labeled spoken digit.

Figure 46. Retained 4 kHz UART run: exact frame addresses, stable spectral peaks, and the final valid COMP code. Rendered from the saved programmed-board UART capture without altering its values. The final packet asserts valid and carries digit code 3.

Table 13. Programmed-board tone evidence by frequency and retained stage.

Applied tone | Indexed stage views | Coverage note
100 Hz | ADC, Hann, WINDOW, FFT, MEL, LOGMEL, DCT | Complete seven-stage set
500 Hz | ADC, Hann, WINDOW, FFT, MEL, LOGMEL, DCT | Complete seven-stage set
1 kHz | ADC, Hann, WINDOW, FFT, MEL, LOGMEL, DCT | Complete seven-stage set shown above
2 kHz | ADC, Hann, WINDOW, FFT, MEL, LOGMEL | No retained DCT plot for this run
4 kHz | ADC, Hann, WINDOW, FFT, MEL, DCT | No retained LOGMEL plot for this run

Appendix B collects the remaining 26 retained tone plots. Across the sweep, the dominant FFT region moves upward as the applied frequency rises, and the MEL concentration moves into higher bands. These programmed-board captures complement the corrected bin-address regression with historical end-to-end observations.

## 17 Retained FPGA-Computed Spoken-Digit Outputs and Separability Results

The retained startup/test collection contains 30 labeled utterances acquired through the FPGA-UART workflow: digits 0 through 9 with three trials each [7]. These are not MATLAB-generated MFCC examples. For every recording, the programmed FPGA computed and exported the 16,384-sample ADC record and all 63 WINDOW, FFT, MEL, LOGMEL, and DCT frames; the plots in this section render those exact exported integer words. MATLAB was used to parse, store, and plot the UART words and, in Section 17.2, to apply the COMP-compatible leave-one-out distance analysis. The retained representations also supplied the 480 populated 128-bit words used to initialize the writable reference RAM before runtime speaker-specific enrollment.

## 17.1 One retained spoken-input path from samples to coefficients

Figure 47. Retained spoken-input experiment: ADC waveform. Distinct spoken-input figure retained in the project archive. The recorded waveform has a time-localized speech envelope rather than the constant amplitude of a stationary tone. It is the physical signal described by the following maps.

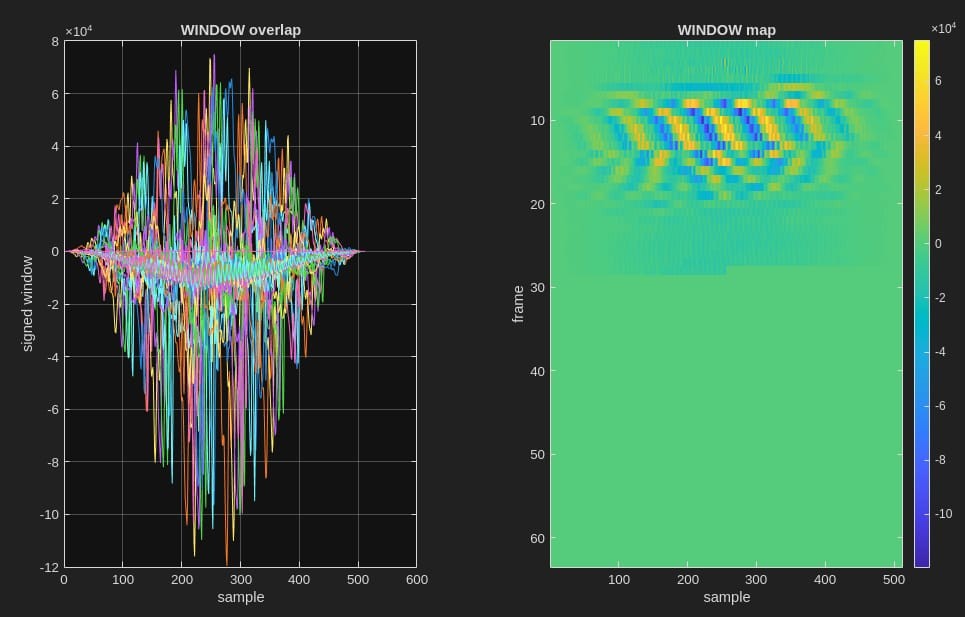
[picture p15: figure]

Figure 48. Retained spoken-input experiment: WINDOW frame sequence. Distinct spoken-input figure retained in the project archive. The same speech interval appears across overlapping tapered frames, preserving transitions that would otherwise fall on an arbitrary frame boundary.

Figure 49. Retained spoken-input experiment: FFT frame map. Distinct spoken-input figure retained in the project archive. Time-varying spectral concentrations follow the utterance rather than staying at one tone bin. This is the frequency structure needed by the perceptual filter bank.

Figure 50. Retained spoken-input experiment: MEL frame map. Distinct spoken-input figure retained in the project archive. The 256-bin spectrum is reorganized into 32 broader bands while its time-varying contour remains visible.

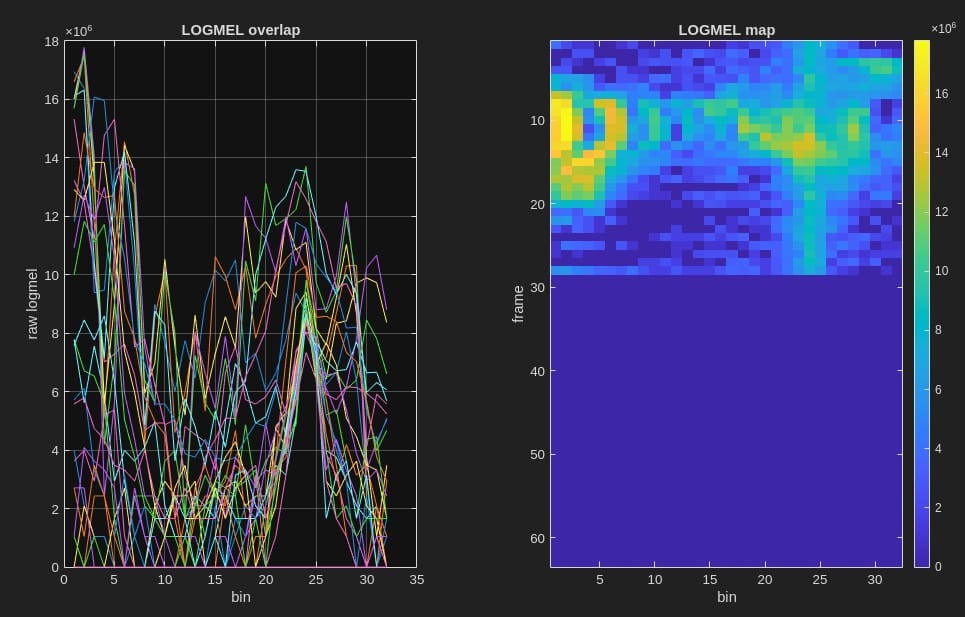
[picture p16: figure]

Figure 51. Retained spoken-input experiment: LOGMEL frame map. Distinct spoken-input figure retained in the project archive. Logarithmic compression reduces absolute dynamic range without erasing the band pattern.

Figure 52. Retained spoken-input experiment: DCT frame map. Distinct spoken-input figure retained in the project archive. Eight signed non-DC coefficients retain a compact, changing signature that can be compared over the selected 16-frame interval.

Figure 53. Saved digit-9 UART record: ADC envelope, MEL-energy onset, DCT map, and selected 16-frame window.
Rendered from the retained dataset record; all plotted arrays are saved FPGA-UART values. The six preceding retained figures show the complete ADC-to-DCT representation. This focused view makes their timing relationship readable: the record has an estimated SNR of 27.91 dB, the first MEL-energy threshold crossing selects frame 7, peak MEL energy occurs at frame 13, and the dashed DCT-map rectangle marks the exact 16-frame feature window passed to SAD/L1 comparison. The saved record still contains 63 WINDOW, FFT, MEL, LOGMEL, and DCT frames; those counts are stated here rather than compressed into an unreadable plot annotation.

## 17.2 SAD/L1 decision and leave-one-out separation

Applying the implemented 16-frame by eight-coefficient SAD/L1 rule offline to the exact DCT words computed by the FPGA gave 30/30 leave-one-out decisions on this 30-record development set. Rebuilding the 480 populated reference words from the same retained FPGA values produced zero mismatches with the COE. The 30/30 figure is therefore an offline separability analysis of FPGA-computed features, not a retained log of 30 on-board COMP decisions. The focused COMP simulation in Section 12.5 separately exercises the RTL decision path. Because the recordings predate the FFT/MEL address fixes, this result is used to check the SAD/L1 rule and seed packing, not current live accuracy.

Table 14. Retained FPGA-UART startup/test collection under the COMP SAD/L1 distance convention.

Digit | Retained trials | Correct leave-one-out decisions
0 | 3 | 3 / 3
1 | 3 | 3 / 3
2 | 3 | 3 / 3
3 | 3 | 3 / 3
4 | 3 | 3 / 3
5 | 3 | 3 / 3
6 | 3 | 3 / 3
7 | 3 | 3 / 3
8 | 3 | 3 / 3
9 | 3 | 3 / 3
Total | 30 | 30 / 30

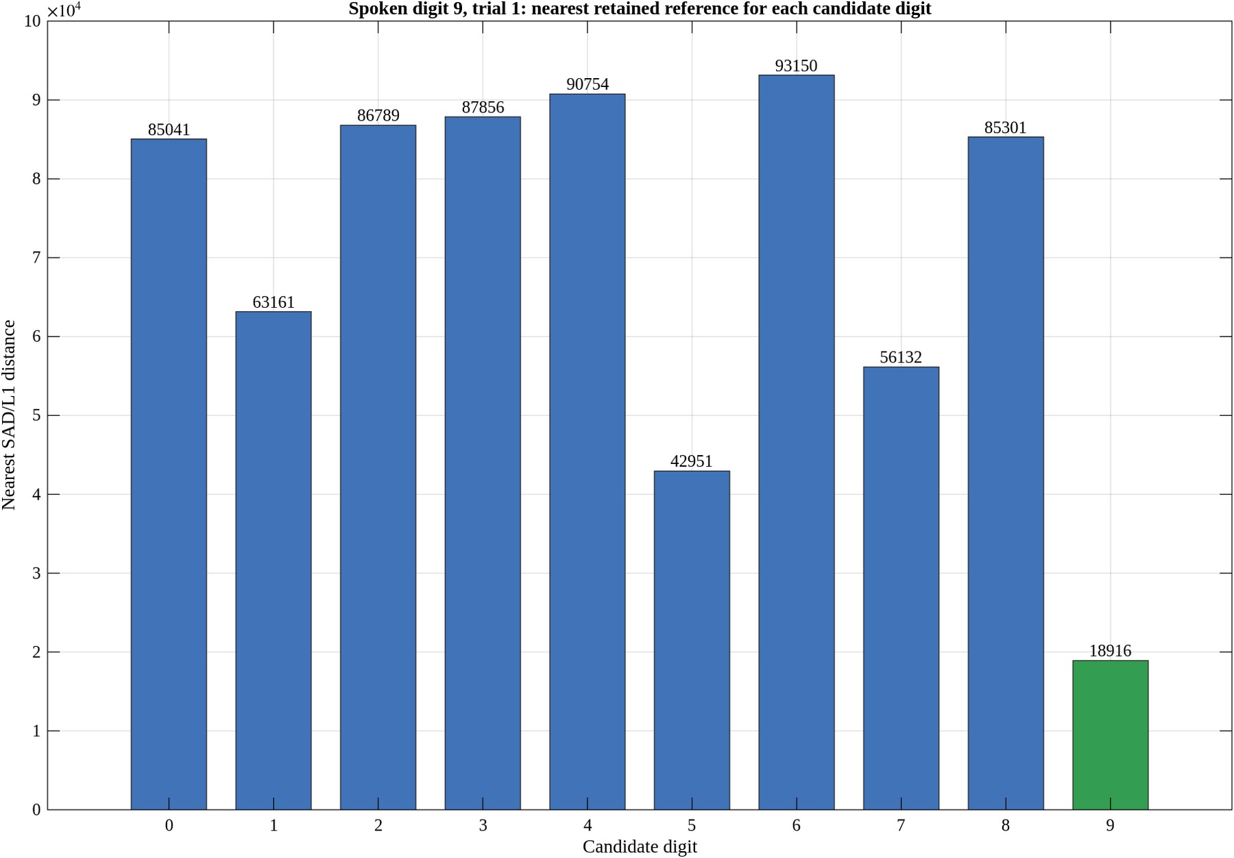
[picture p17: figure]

Figure 54. Digit 9, trial 1: nearest retained reference for each candidate digit. Rendered from the retained C1-to-C8 feature records with the implemented 16-frame SAD/L1 metric.
The correct digit-9 distance is 18,916. The nearest wrong digit is 5 at 42,951, approximately 2.27 times farther away; the remaining digit-wise nearest distances range from 56,132 to 93,150. The plot therefore explains this individual decision rather than presenting the result as an unexplained label.

Figure 55. Leave-one-out confusion matrix for all 30 retained FPGA-UART utterances. Rendered from three retained recordings per digit using the COMP-compatible SAD/L1 convention.
All 30 leave-one-out decisions lie on the diagonal for this development set.

Figure 56. Nearest retained-recording distance versus nearest wrong-digit distance for all 30 queries.
Rendered from the retained FPGA-UART dataset using leave-one-out SAD/L1 comparison. For every query, the nearest retained recording is closer than the nearest example carrying a different digit. Showing both distances prevents the perfect confusion matrix from becoming a context-free score: it exposes the separation margin for every digit/trial and identifies recordings that are relatively easier or harder under this small dataset.

## 18 Vivado Implementation and Clock Engineering

The current RTL was synthesized, placed, routed, and converted into a Basys 3 bitstream on 27 July 2026 [6]. It uses the 100 MHz board clock as a single processing domain; the ADC's 33.333 MHz transaction enable is derived inside that domain rather than generated as a second clock. The 3 June programmed-board captures belong to an earlier development bitstream and are used only as historical evidence of acquisition and memory population. Current post-correction simulation, current implementation reports, and historical board captures are identified separately.

## 18.1 The 36 MHz attempt and the final divide-by-three decision

During development I attempted a generated ADC-controller clock near the original 36 MHz objective. Behavioral simulation alone did not expose the practical difficulty. The generated clock placed control and memory activity across a more sensitive boundary, implementation iterations were unstable, and board behavior could differ from the simulated receiver even during a diagnostic in which the serial input was forced low. I added synchronizer/clock-path constraints, I/O registers, KEEP and DONT_TOUCH attributes, and a localized ADC placement region while investigating the problem.
I ultimately judged the exact nominal tick to be the wrong priority. Advancing the receiver every three 100 MHz clocks produces 33.333 MHz, approximately 7.4% below 36 MHz, while eliminating the separate clock-domain dependency. For a speech recognizer, that uniform difference is safer than retaining an inconsistent acquisition implementation. Only the retained final 100 MHz implementation results are reported. The current routed internal timing and the historical programmed-board behavior are separate results.
Table 15. Final timing result and its relationship to the ADC clock decision.
Timing item | 27 July routed value | Interpretation
Primary clock | 100.000 MHz | One synchronous processing domain
WNS / TNS | +0.630 ns / 0.000 ns | Positive setup margin and no setup-failing endpoints
WHS / THS | +0.014 ns / 0.000 ns | Positive hold margin and no hold-failing endpoints
Routing | 12,825 / 12,825 routable nets; 0 errors | The complete design is fully routed
External I/O delays | Not constrained | No board-level SPI or other interface timing-closure claim
ADC controller enable | 33.333 MHz | Single-domain divide-by-three transaction cadence
ADC SCLK | Approximately 16.667 MHz | Clock toggles over alternating receive/decode phases
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

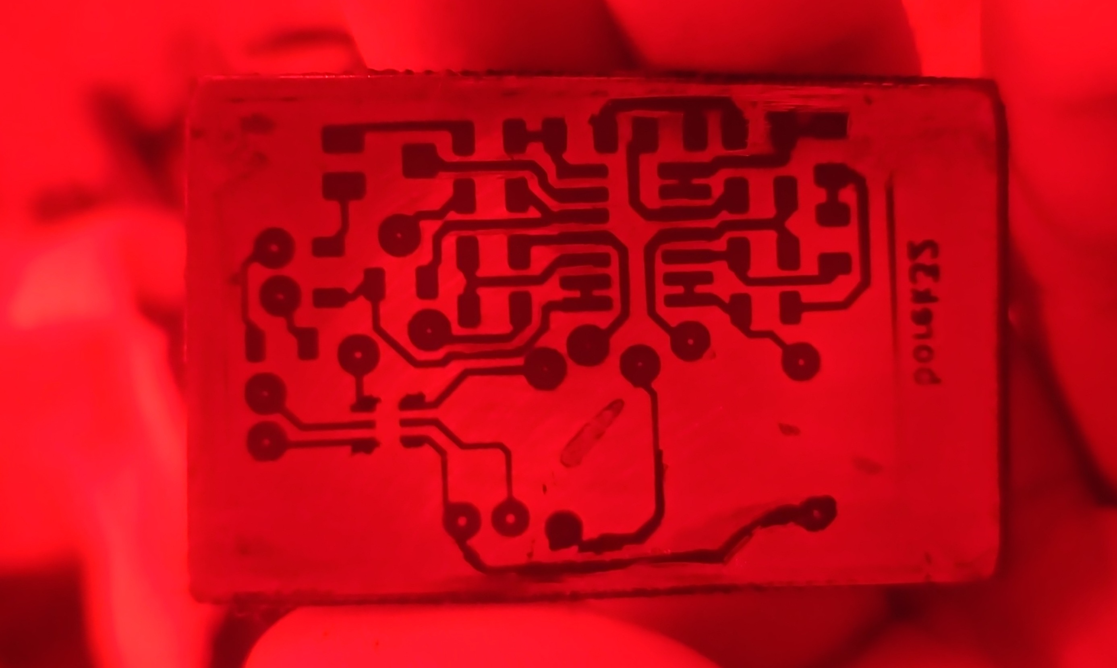
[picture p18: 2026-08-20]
hardware/homefab_mic_adc_pcb/photos/20260716_early_defective_uv_trial.jpg

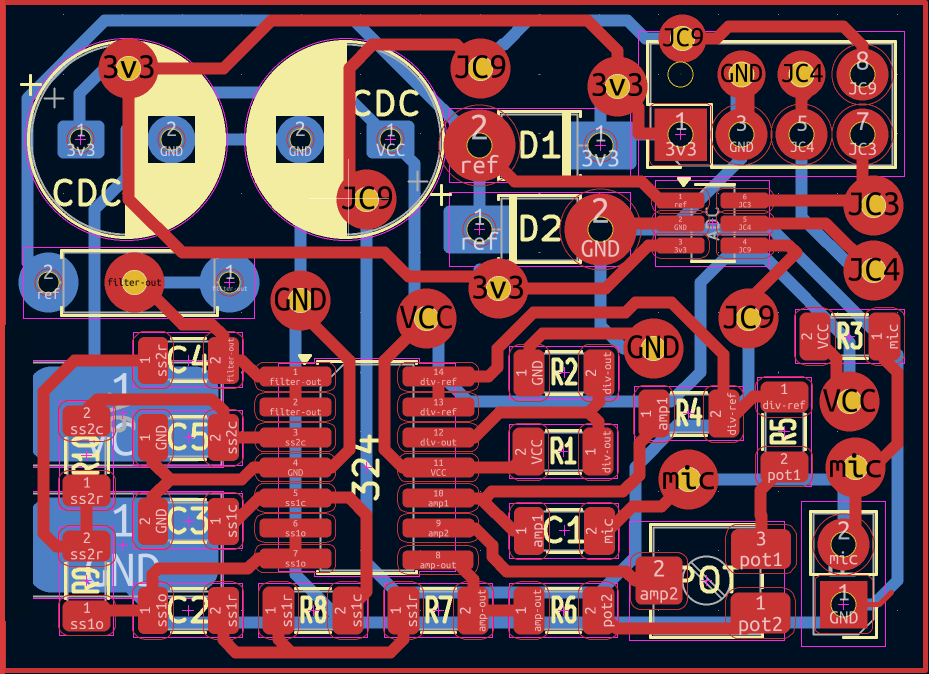
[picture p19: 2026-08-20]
hardware/homefab_mic_adc_pcb/report_assets/derived/homefab_all_layers_working_view.png

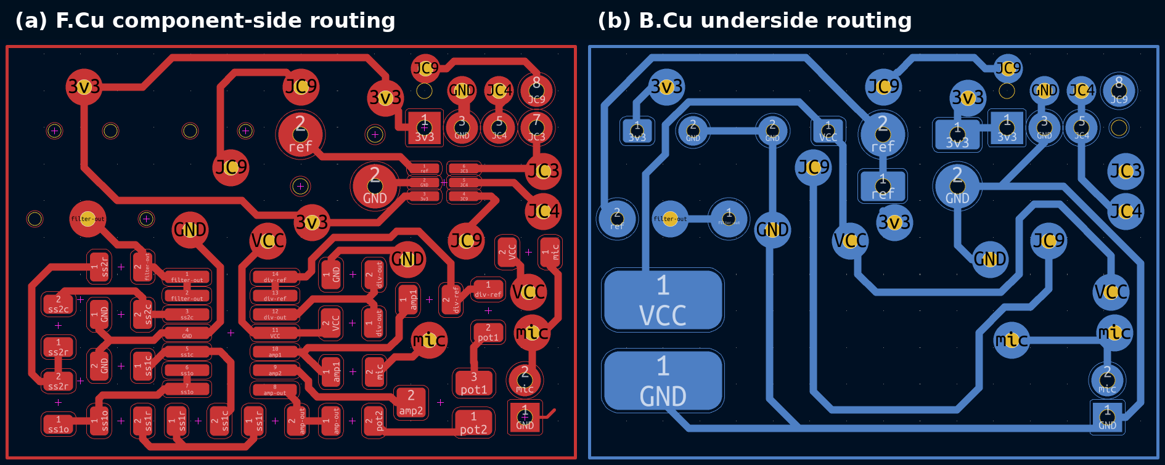
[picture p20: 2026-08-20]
hardware/homefab_mic_adc_pcb/report_assets/derived/homefab_named_net_layers.png

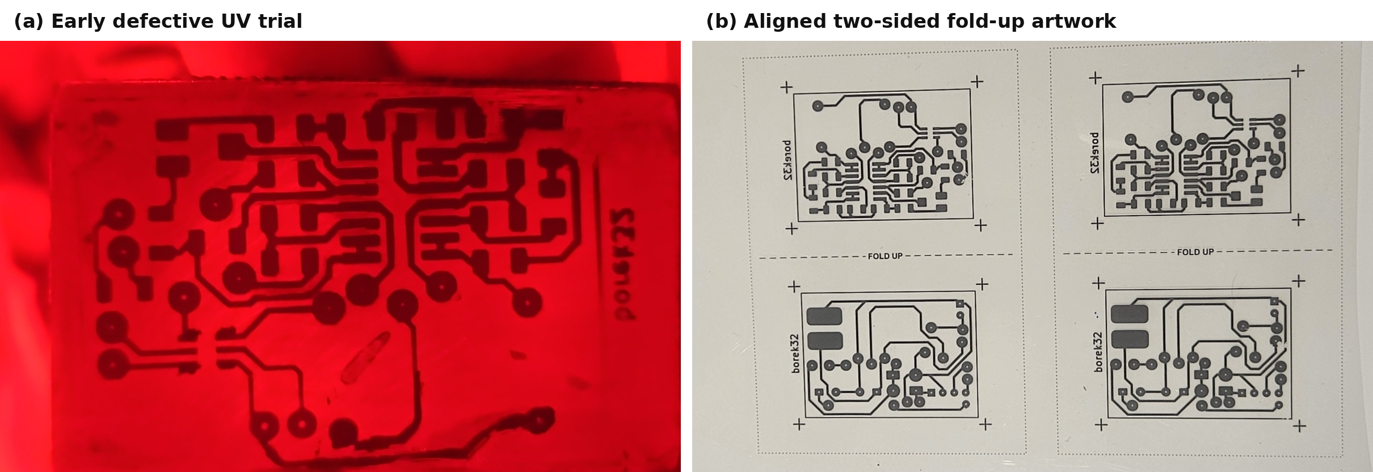
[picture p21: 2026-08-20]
hardware/homefab_mic_adc_pcb/report_assets/derived/homefab_development_progression.png

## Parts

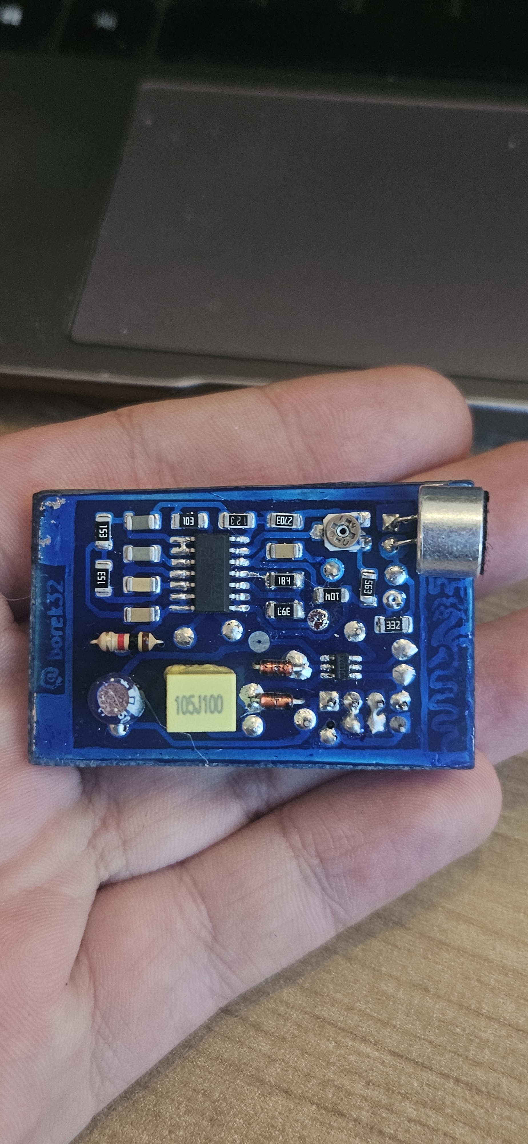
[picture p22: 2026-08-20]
hardware/homefab_mic_adc_pcb/photos/20260819_190754_component_side.jpg

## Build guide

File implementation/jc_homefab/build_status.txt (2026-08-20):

RESULT=PASS
IMPLEMENTATION=write_bitstream Complete!
SETUP_SLACK_NS=0.671
HOLD_SLACK_NS=0.020
DRC_ADVISORY=11
DRC_WARNING=0
DRC_CRITICAL_WARNING=0
DRC_ERROR=0
TOP=top_module
PART=xc7a35tcpg236-1
CONSTRAINT_SET=newpcb_constrs
PORT_COUNT=39
ADC_CS_OUT=P17/JC9
ADC_SPI_MISO=P18/JC4
ADC_SPI_CLK=N17/JC3

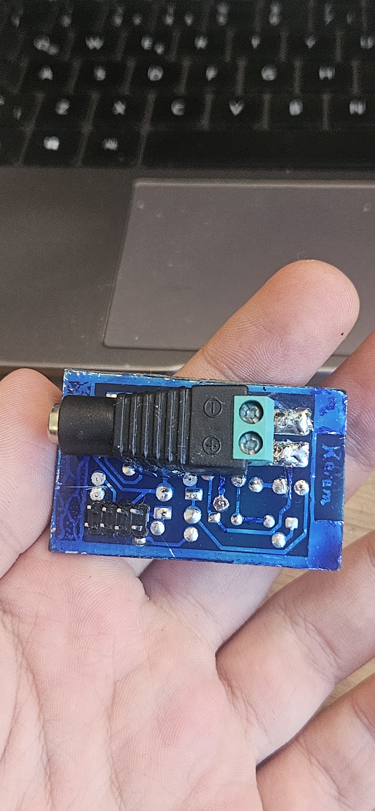
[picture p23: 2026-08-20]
hardware/homefab_mic_adc_pcb/photos/20260819_190748_solder_side.jpg

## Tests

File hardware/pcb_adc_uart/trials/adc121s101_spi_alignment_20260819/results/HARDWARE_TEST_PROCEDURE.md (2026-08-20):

# ADC121S101 alignment trial: future hardware procedure

Current status: historical JTAG configuration **PASS**; ADC endpoint capture
**NOT RUN**. Programming establishes FPGA configuration only.

## Rebuild and identity gate

Use the standalone project's optional candidate-source argument to create a
fresh external build, then calculate the generated bitstream's SHA-256. Program
only after visually inspecting the intended live JTAG target:

```bash
vivado -mode batch -notrace \
  -source ../hardware/program_candidate.tcl \
  -tclargs /external/results/PCB.bit \
  YOUR_EXPLICIT_JTAG_TARGET_SUBSTRING \
  YOUR_EXPLICIT_64_HEX_BITSTREAM_SHA256
```

No device serial, UART port, bitstream or log path is embedded in this release.
Retain the fresh programming transcript outside the checkout.

## Electrical safety

1. Establish common ground between FPGA, ADC board and voltage source.
2. Measure ADC supply `VA`; do not assume exactly 3.300 V.
3. Never apply `Vin > VA`, and never drive an unpowered ADC input.
4. Use a low-impedance midscale source.
5. Use approximately `VA - 50 mV` for the upper point to avoid overshoot.
6. Release BTNU before changing analog voltage.

## Capture sequence

Call `../hardware/capture_adc121s101_trial.m` with an explicit UART port and
external output directory. The UART format is 921600 baud, 8 data bits, no
parity, one stop bit; each signed word is transmitted low byte first.

For each voltage point:

1. Keep BTNU released; press/release BTNC and require LD0 high.
2. Apply the input and record DMM measurements of `VA` and `Vin`.
3. Open and flush the explicit UART endpoint while BTNU remains released.
4. Press and hold BTNU only after the flush; capture an even byte count.
5. Release BTNU before disconnecting or changing voltage.
6. Retain raw bytes, decoded values, time, source/bitstream hashes, board tag,
   `VA`, and `Vin` in the external evidence directory.

Reject a run after a USB disconnect, odd byte count, or decoded value outside
`-2048..+2047`.

## Expected values and empty result record

`ideal_code = min(4095, floor(4096 * Vin / VA))`; centered result is
`ideal_code - 2048`.

| Field | Ground | Midscale | Upper point |
| --- | --- | --- | --- |
| Capture time | NOT RUN | NOT RUN | NOT RUN |
| Measured `VA` | NOT RUN | NOT RUN | NOT RUN |
| Measured `Vin` | NOT RUN | NOT RUN | NOT RUN |
| First raw UART words | NOT RUN | NOT RUN | NOT RUN |
| Median / range | NOT RUN | NOT RUN | NOT RUN |
| PASS / FAIL | NOT RUN | NOT RUN | NOT RUN |

Ground alone cannot distinguish a corrected receiver from a lost-MSB case.
Measured midscale and the upper point are decisive.

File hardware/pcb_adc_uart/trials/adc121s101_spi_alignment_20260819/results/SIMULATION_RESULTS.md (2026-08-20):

# ADC121S101 datasheet-derived behavioral RTL simulation

Date: 19 August 2026

## Evidence boundary

This is RTL simulation evidence, not a bench result. The purpose-built digital
behavioral model derives selected serial behavior from the TI ADC121S101 Rev. H
datasheet and uses the 2.7-3.6 V worst-case values `tACC=40 ns`, `tEN=20 ns`,
and `tDIS=25 ns`. It models the phase-dependent optional fourth leading zero,
the `Z2/Z1/Z0` prefix, `DB11..DB0` MSB-first, 16 falling edges, and TRI-STATE
after the last edge. It does not model analog conversion, board-level signal
integrity, or assert every acquisition, quiet-time, and throughput requirement.

## Stimulus and assertions

- Frame zero deliberately carries raw code `A5A` as a conservative dummy and
  must be discarded by this trial. This does not claim that every `start_in`
  transition is equivalent to ADC power-up or that TI requires that discard.
- Six following groups each contain 32 identical conversions: `000`, `001`,
  `7FF`, `800`, `801`, and `FFF`.
- Every closed frame must have exactly 16 falling SCLK edges.
- CS must precede the first falling SCLK edge by at least 10 ns.
- UART is decoded low byte first and compared against the centered signed word.
- The testbench accelerates UART to 10,000,000 baud. It checks UART framing,
  byte order, and word values; it does not verify the production 921600 baud.

## Preserved baseline: FAIL

The preserved source produced 12 falling edges in its first frame and 17 in
later frames. Later frames also asserted CS and the first falling SCLK edge
together, giving 0 ns setup. The baseline log therefore contains the expected
frame-count, setup, and value failures.

The model does not claim to reproduce the exact near-zero full-scale bench
value. Once the invalid baseline receiver samples SDATA after TRI-STATE, the
physical input level is uncontrolled and need not resolve like the simulator.

Evidence: `baseline_simulation_xsim.log` and `baseline_simulation.wdb`.

## Isolated candidate: PASS

| ADC raw | UART word | Signed result |
|---:|---:|---:|
| `000` | `F800` | -2048 |
| `001` | `F801` | -2047 |
| `7FF` | `FFFF` | -1 |
| `800` | `0000` | 0 |
| `801` | `0001` | 1 |
| `FFF` | `07FF` | 2047 |

The deliberately injected `A5A` first frame did not contaminate the first
average. Every candidate frame that closed during this simulation contained
exactly 16 falling edges, and no CS-setup, UART, frame-count, or signed-value
assertion failed. The first-frame monitor reported 55.556 ns from CS assertion
to the first falling SCLK edge and reported the optional fourth leading zero as
exercised. The final PASS occurred at 340.385 us.

Evidence: `candidate_simulation_xsim.log` and `candidate_simulation.wdb`.

## Reproduction

From the `sim/` directory:

```bash
./run_xsim.sh
./run_xsim.sh ../baseline/PCB.vhd
```

The first command must exit zero. The baseline command is expected to exit one.

## Remaining gate

Hardware is NOT RUN. The candidate becomes a confirmed fix only when a new
bitstream produces retained UART captures near -2048 at 0 V, 0 at midscale,
and +2047 at full scale.

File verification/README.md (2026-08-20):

# VHDL, XSim and MATLAB verification

This directory contains the VHDL-bench inputs and retained outputs, MATLAB
fixed-point cross-checks, IP memory images, and the bounded XSim runner. A clean
run operates on the copy created in an external Vivado project, so new output
does not modify the public checkout.

Flow:

1. A VHDL bench reads `ref_data/*.txt`.
2. It writes integer results to `tb_output/*.txt`.
3. The matching script in `matlab/` computes an independent fixed-point result
   and compares it with the fresh bench output.

The default runner covers nine module benches. `tb_ADC` is deliberately
rejected because the long acquisition simulation is CPU-intensive and requires
active monitoring. `tb_top_module` is opt-in.

After recreating the project with the external paths from the root
`REPRODUCIBILITY.md`, run XSim from that external runtime directory and MATLAB
from the external build directory:

```bash
repo_root=$(pwd -P)
build_dir=$(readlink -m ../mfcc-build-v1.0.0)
runtime_dir=$(readlink -m ../mfcc-runtime-v1.0.0)

(
  cd "$runtime_dir"
  vivado -mode batch -notrace \
    -journal "$runtime_dir/02-safe-testbenches.jou" \
    -log "$runtime_dir/02-safe-testbenches.log" \
    -source "$repo_root/verification/run_testbenches.tcl" \
    -tclargs "$build_dir"
)

matlab_lock=${XDG_RUNTIME_DIR:-/tmp}/mfcc-release-matlab-$(id -u).lock
matlab_log="$runtime_dir/matlab-safe.log"
(
  set -euo pipefail
  if ! flock -n 9; then
    echo "another MFCC release MATLAB gate is active" >&2
    exit 2
  fi
  if pgrep -x MATLAB >/dev/null 2>&1; then
    echo "another MATLAB process is active; wait before running this gate" >&2
    exit 2
  fi
  cd "$build_dir"
  if ! matlab -batch \
    "run('verification/matlab/run_safe_module_verifiers.m'); diary('off'); clear cleanup_diary cleanup_state; fprintf('MATLAB_CALLER_CLEANUP_PASS\n');" \
    2>&1 | tee "$matlab_log"; then
    echo "MATLAB verification process failed" >&2
    exit 1
  fi
  grep -Fqx 'SAFE_MODULE_VERIFIERS_PASS count=9' "$matlab_log"
  grep -Fqx 'MATLAB_CALLER_CLEANUP_PASS' "$matlab_log"
) 9>"$matlab_lock"
```

The caller-side cleanup after `run(...)` avoids a MATLAB R2025b allocator abort
during batch-process teardown; it does not bypass any checker. The lock and
process check keep this memory-intensive gate from overlapping another MATLAB
job. A valid run exits zero and emits both the aggregate and caller-cleanup PASS
markers.

The FFT gate requires the DUT peak address to match the expected bin, each
integer-reference magnitude error to remain within 64 counts, and all 256
words to match the retained AMD XFFT v9.1 bit-accurate reference exactly.

The retained `tb_output/` files establish what was checked during development;
they are not silently substituted for a fresh run.

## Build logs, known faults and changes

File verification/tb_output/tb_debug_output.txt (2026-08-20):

AABBCC00
000001FB
00000059
AABBCC01
000001FB
000001FC
000001FD
000001FE
000001FF
00000000
00000001
00000002
00000003
00000004
00000005
00000006
00000007
00000008
00000009
0000000A
0000000B
0000000C
0000000D
0000000E
0000000F
00000010
00000011
00000012
00000013
00000014
00000015
00000016
00000017
00000018
00000019
0000001A
0000001B
0000001C
0000001D
0000001E
0000001F
00000020
00000021
00000022
00000023
00000024
00000025
00000026
00000027
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
000000AA
000000AB
000000AC
000000AD
000000AE
000000AF
000000B0
000000B1
000000B2
000000B3
000000B4
000000B5
000000B6
000000B7
000000B8
000000B9
000000BA
000000BB
000000BC
000000BD
000000BE
000000BF
000000C0
000000C1
000000C2
000000C3
000000C4
000000C5
000000C6
000000C7
000000C8
000000C9
000000CA
000000CB
000000CC
000000CD
000000CE
000000CF
000000D0
000000D1
000000D2
000000D3
000000D4
000000D5
000000D6
000000D7
000000D8
000000D9
000000DA
000000DB
000000DC
000000DD
000000DE
000000DF
000000E0
000000E1
000000E2
000000E3
000000E4
000000E5
000000E6
000000E7
000000E8
000000E9
000000EA
000000EB
000000EC
000000ED
000000EE
000000EF
000000F0
000000F1
000000F2
000000F3
000000F4
000000F5
000000F6
000000F7
000000F8
000000F9
000000FA
000000FB
000000FC
000000FD
000000FE
000000FF
00000100
00000101
00000102
00000103
00000104
00000105
00000106
00000107
00000108
00000109
0000010A
0000010B
0000010C
0000010D
0000010E
0000010F
00000110
00000111
00000112
00000113
00000114
00000115
00000116
00000117
00000118
00000119
0000011A
0000011B
0000011C
0000011D
0000011E
0000011F
00000120
00000121
00000122
00000123
00000124
00000125
00000126
00000127
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
000001AA
000001AB
000001AC
000001AD
000001AE
000001AF
000001B0
000001B1
000001B2
000001B3
000001B4
000001B5
000001B6
000001B7
000001B8
000001B9
000001BA
000001BB
000001BC
000001BD
000001BE
000001BF
000001C0
000001C1
000001C2
000001C3
000001C4
000001C5
000001C6
000001C7
000001C8
000001C9
000001CA
000001CB
000001CC
000001CD
000001CE
000001CF
000001D0
000001D1
000001D2
000001D3
000001D4
000001D5
000001D6
000001D7
000001D8
000001D9
000001DA
000001DB
000001DC
000001DD
000001DE
000001DF
000001E0
000001E1
000001E2
000001E3
000001E4
000001E5
000001E6
000001E7
000001E8
000001E9
000001EA
000001EB
000001EC
000001ED
000001EE
000001EF
000001F0
000001F1
000001F2
000001F3
000001F4
000001F5
000001F6
000001F7
000001F8
000001F9
000001FA
AABBCC02
00020000
00020001
00020002
00020003
00020004
00020005
00020006
00020007
00020008
00020009
0002000A
0002000B
0002000C
0002000D
0002000E
0002000F
00020010
00020011
00020012
00020013
00020014
00020015
00020016
00020017
00020018
00020019
0002001A
0002001B
0002001C
0002001D
0002001E
0002001F
00020020
00020021
00020022
00020023
00020024
00020025
00020026
00020027
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
000200AA
000200AB
000200AC
000200AD
000200AE
000200AF
000200B0
000200B1
000200B2
000200B3
000200B4
000200B5
000200B6
000200B7
000200B8
000200B9
000200BA
000200BB
000200BC
000200BD
000200BE
000200BF
000200C0
000200C1
000200C2
000200C3
000200C4
000200C5
000200C6
000200C7
000200C8
000200C9
000200CA
000200CB
000200CC
000200CD
000200CE
000200CF
000200D0
000200D1
000200D2
000200D3
000200D4
000200D5
000200D6
000200D7
000200D8
000200D9
000200DA
000200DB
000200DC
000200DD
000200DE
000200DF
000200E0
000200E1
000200E2
000200E3
000200E4
000200E5
000200E6
000200E7
000200E8
000200E9
000200EA
000200EB
000200EC
000200ED
000200EE
000200EF
000200F0
000200F1
000200F2
000200F3
000200F4
000200F5
000200F6
000200F7
000200F8
000200F9
000200FA
000200FB
000200FC
000200FD
000200FE
000200FF
00020100
00020101
00020102
00020103
00020104
00020105
00020106
00020107
00020108
00020109
0002010A
0002010B
0002010C
0002010D
0002010E
0002010F
00020110
00020111
00020112
00020113
00020114
00020115
00020116
00020117
00020118
00020119
0002011A
0002011B
0002011C
0002011D
0002011E
0002011F
00020120
00020121
00020122
00020123
00020124
00020125
00020126
00020127
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
000201AA
000201AB
000201AC
000201AD
000201AE
000201AF
000201B0
000201B1
000201B2
000201B3
000201B4
000201B5
000201B6
000201B7
000201B8
000201B9
000201BA
000201BB
000201BC
000201BD
000201BE
000201BF
000201C0
000201C1
000201C2
000201C3
000201C4
000201C5
000201C6
000201C7
000201C8
000201C9
000201CA
000201CB
000201CC
000201CD
000201CE
000201CF
000201D0
000201D1
000201D2
000201D3
000201D4
000201D5
000201D6
000201D7
000201D8
000201D9
000201DA
000201DB
000201DC
000201DD
000201DE
000201DF
000201E0
000201E1
000201E2
000201E3
000201E4
000201E5
000201E6
000201E7
000201E8
000201E9
000201EA
000201EB
000201EC
000201ED
000201EE
000201EF
000201F0
000201F1
000201F2
000201F3
000201F4
000201F5
000201F6
000201F7
000201F8
000201F9
000201FA
000201FB
000201FC
000201FD
000201FE
000201FF
AABBCC03
30000000
30000001
30000002
30000003
30000004
30000005
30000006
30000007
30000008
30000009
3000000A
3000000B
3000000C
3000000D
3000000E
3000000F
30000010
30000011
30000012
30000013
30000014
30000015
30000016
30000017
30000018
30000019
3000001A
3000001B
3000001C
3000001D
3000001E
3000001F
30000020
30000021
30000022
30000023
30000024
30000025
30000026
30000027
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
300000AA
300000AB
300000AC
300000AD
300000AE
300000AF
300000B0
300000B1
300000B2
300000B3
300000B4
300000B5
300000B6
300000B7
300000B8
300000B9
300000BA
300000BB
300000BC
300000BD
300000BE
300000BF
300000C0
300000C1
300000C2
300000C3
300000C4
300000C5
300000C6
300000C7
300000C8
300000C9
300000CA
300000CB
300000CC
300000CD
300000CE
300000CF
300000D0
300000D1
300000D2
300000D3
300000D4
300000D5
300000D6
300000D7
300000D8
300000D9
300000DA
300000DB
300000DC
300000DD
300000DE
300000DF
300000E0
300000E1
300000E2
300000E3
300000E4
300000E5
300000E6
300000E7
300000E8
300000E9
300000EA
300000EB
300000EC
300000ED
300000EE
300000EF
300000F0
300000F1
300000F2
300000F3
300000F4
300000F5
300000F6
300000F7
300000F8
300000F9
300000FA
300000FB
300000FC
300000FD
300000FE
300000FF
AABBCC04
40000000
40000001
40000002
40000003
40000004
40000005
40000006
40000007
40000008
40000009
4000000A
4000000B
4000000C
4000000D
4000000E
4000000F
40000010
40000011
40000012
40000013
40000014
40000015
40000016
40000017
40000018
40000019
4000001A
4000001B
4000001C
4000001D
4000001E
4000001F
AABBCC05
50000000
50000001
50000002
50000003
50000004
50000005
50000006
50000007
50000008
50000009
5000000A
5000000B
5000000C
5000000D
5000000E
5000000F
50000010
50000011
50000012
50000013
50000014
50000015
50000016
50000017
50000018
50000019
5000001A
5000001B
5000001C
5000001D
5000001E
5000001F
AABBCC06
00006000
00006001
00006002
00006003
00006004
00006005
00006006
00006007
AA5503CC

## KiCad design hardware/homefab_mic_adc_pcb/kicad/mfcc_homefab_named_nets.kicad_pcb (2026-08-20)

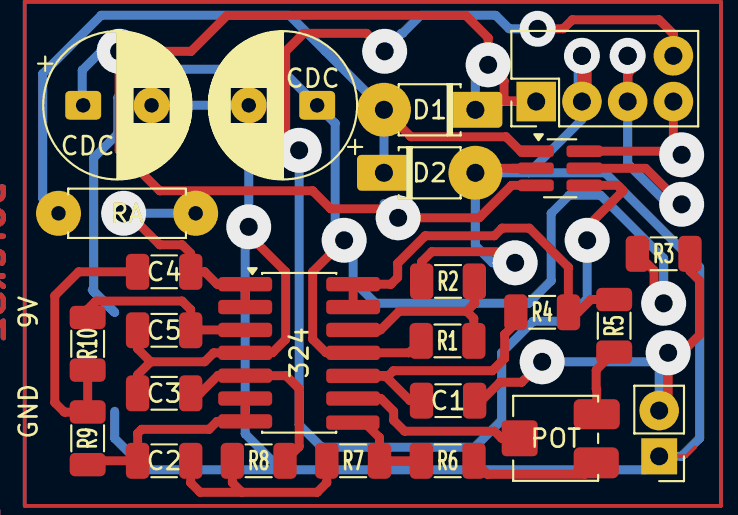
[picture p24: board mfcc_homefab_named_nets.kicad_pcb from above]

Board: 2 copper layers, 24 parts (0 on the bottom side), 18 nets.

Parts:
9V: SolderWirePad_1x01_SMD_4x8mm
324: SO-14_3.9x8.65mm_P1.27mm
C1, C2, C3, C4, C5: C_1206_3216Metric
CDC: CP_Radial_D8.0mm_P3.80mm
CDC#2: CP_Radial_D8.0mm_P3.80mm
D1, D2: D_T-1_P5.08mm_Horizontal
GND: SolderWirePad_1x01_SMD_4x8mm
POT: Potentiometer_Bourns_3314J_Vertical
R1, R2, R3, R4, R5, R6, R7, R8, R9, R10: R_1206_3216Metric
RA: R_Axial_DIN0207_L6.3mm_D2.5mm_P7.62mm_Horizontal

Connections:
/3v3: CDC#2.1, D1.1
/amp1: 324.10, C1.1, R4.1
/amp2: 324.9, POT.2
/amp-out: 324.8, R6.1, R7.2
/div-out: 324.12, R1.1, R2.2
/div-ref: 324.13, 324.14, R4.2, R5.1
/filter-out: 324.1, 324.2, C4.2, RA.1
/mic: C1.2, R3.1
/pot1: POT.3, R5.2
/pot2: POT.1, R6.2
/ref: D1.2, D2.1, RA.2
/ss1c: 324.5, C3.1, R8.2
/ss1o: 324.6, 324.7, C2.1, R9.1
/ss1r: C2.2, R7.1, R8.1
/ss2c: 324.3, C5.2, R10.2
/ss2r: C4.1, R9.2, R10.1
GND: 324.4, C3.2, C5.1, CDC.2, CDC#2.2, D2.2, GND.1, R2.1
VCC: 9V.1, 324.11, CDC.1, R1.2, R3.2

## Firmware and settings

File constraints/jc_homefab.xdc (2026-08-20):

# ==============================================================================
# BITSTREAM CONFIGURATION
# ==============================================================================
set_property CFGBVS VCCO [current_design]
set_property CONFIG_VOLTAGE 3.3 [current_design]

# ==============================================================================
# CLOCK SIGNAL (100 MHz)
# ==============================================================================
set_property PACKAGE_PIN W5 [get_ports clock_in]
set_property IOSTANDARD LVCMOS33 [get_ports clock_in]
create_clock -add -name sys_clk_pin -period 10.00 -waveform {0 5} [get_ports clock_in]

# This file constrains the internal 100 MHz processing clock. External SPI and
# board-interface input/output delays are not yet characterized or constrained.

# ==============================================================================
# BUTTONS
# ==============================================================================
# Center Button (Reset)
set_property PACKAGE_PIN U18 [get_ports reset_in]
set_property IOSTANDARD LVCMOS33 [get_ports reset_in]

# Up Button (Start ADC)
set_property PACKAGE_PIN T18 [get_ports start_in]
set_property IOSTANDARD LVCMOS33 [get_ports start_in]

# Right Button (Increment selected trial)
set_property PACKAGE_PIN T17 [get_ports trial_inc_in]
set_property IOSTANDARD LVCMOS33 [get_ports trial_inc_in]

# Left Button (Decrement selected trial)
set_property PACKAGE_PIN W19 [get_ports trial_dec_in]
set_property IOSTANDARD LVCMOS33 [get_ports trial_dec_in]

# Down Button (Flush compare reference RAM)
set_property PACKAGE_PIN U17 [get_ports flush]
set_property IOSTANDARD LVCMOS33 [get_ports flush]


# ==============================================================================
# LEDs (Status Indicators)
# ==============================================================================
set_property -dict { PACKAGE_PIN E19   IOSTANDARD LVCMOS33 } [get_ports {debug_led_out}];# LD1, debug enabled
set_property -dict { PACKAGE_PIN U14   IOSTANDARD LVCMOS33 } [get_ports {ready_out}];# LD6
set_property -dict { PACKAGE_PIN V14   IOSTANDARD LVCMOS33 } [get_ports {adcbusy}];# LD7
set_property -dict { PACKAGE_PIN V13   IOSTANDARD LVCMOS33 } [get_ports {adcdone}];# LD8
set_property -dict { PACKAGE_PIN V3    IOSTANDARD LVCMOS33 } [get_ports {flush_done}];# LD9

# ==============================================================================
# SPI INTERFACE - NEW ADC PCB ON PMOD JC
# ==============================================================================
# This is the complete alternate constraint file for the new ADC PCB. Use it
# instead of xdc.xdc; never enable both complete files in one constraint set.
# JC10/R18 remains driven by the separate pmod output below and must be left
# electrically unconnected by the ADC PCB unless that connection is intended.

set_property -dict { PACKAGE_PIN P17   IOSTANDARD LVCMOS33 } [get_ports {cs_out}];# JC9
set_property -dict { PACKAGE_PIN P18   IOSTANDARD LVCMOS33 } [get_ports {spi_miso}];# JC4
set_property -dict { PACKAGE_PIN N17   IOSTANDARD LVCMOS33 } [get_ports {spi_clk}];# JC3
# JC1, JC2, JC7, and JC8 are unused by the ADC interface.



set_property -dict { PACKAGE_PIN V17   IOSTANDARD LVCMOS33 } [get_ports {switch}];# SW0, 1=record, 0=compare
set_property -dict { PACKAGE_PIN V16   IOSTANDARD LVCMOS33 } [get_ports {debug_enable_in}];# SW1, 1=debug UART enabled
set_property -dict { PACKAGE_PIN R18   IOSTANDARD LVCMOS33 } [get_ports {pmod}];#Sch name = JC10

# USB UART TX to PC
set_property PACKAGE_PIN A18 [get_ports txd_out]
set_property IOSTANDARD LVCMOS33 [get_ports txd_out]
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

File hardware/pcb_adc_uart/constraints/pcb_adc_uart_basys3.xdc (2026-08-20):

# Standalone constraints for the recovered PCB ADC-to-UART diagnostic.
# Target board: Digilent Basys 3 (xc7a35tcpg236-1)

# Configuration-bank voltage.
set_property CFGBVS VCCO [current_design]
set_property CONFIG_VOLTAGE 3.3 [current_design]

# 100 MHz Basys 3 oscillator.
set_property -dict { PACKAGE_PIN W5 IOSTANDARD LVCMOS33 } [get_ports {clock_in}]
create_clock -add -name sys_clk_pin -period 10.000 -waveform {0.000 5.000} [get_ports {clock_in}]

# Pushbuttons: BTNC resets the diagnostic and BTNU enables acquisition.
set_property -dict { PACKAGE_PIN U18 IOSTANDARD LVCMOS33 } [get_ports {reset_in}]
set_property -dict { PACKAGE_PIN T18 IOSTANDARD LVCMOS33 } [get_ports {start_in}]

# LD0: high when the capture/UART path is ready.
set_property -dict { PACKAGE_PIN U16 IOSTANDARD LVCMOS33 } [get_ports {ready_out}]

# USB-UART transmit path from the FPGA to the FT2232H interface.
set_property -dict { PACKAGE_PIN A18 IOSTANDARD LVCMOS33 } [get_ports {txd_out}]

# Pmod JC: ADC121S101-style three-wire SPI connection. This mirrors the live
# JB3/JB4/JB9 connector-position mapping on JC3/JC4/JC9.
#set_property -dict { PACKAGE_PIN K17 IOSTANDARD LVCMOS33 } [get_ports {JC[0]}] ;# JC1
#set_property -dict { PACKAGE_PIN M18 IOSTANDARD LVCMOS33 } [get_ports {JC[1]}] ;# JC2
set_property -dict { PACKAGE_PIN N17 IOSTANDARD LVCMOS33 } [get_ports {spi_clk}] ;# JC3
set_property -dict { PACKAGE_PIN P18 IOSTANDARD LVCMOS33 } [get_ports {spi_miso}];# JC4
#set_property -dict { PACKAGE_PIN L17 IOSTANDARD LVCMOS33 } [get_ports {JC[4]}] ;# JC7
#set_property -dict { PACKAGE_PIN M19 IOSTANDARD LVCMOS33 } [get_ports {JC[5]}] ;# JC8
set_property -dict { PACKAGE_PIN P17 IOSTANDARD LVCMOS33 } [get_ports {cs_out}]   ;# JC9
#set_property -dict { PACKAGE_PIN R18 IOSTANDARD LVCMOS33 } [get_ports {JC[7]}] ;# JC10

# Previous Pmod JB wiring retained as a disabled fallback.
#set_property -dict { PACKAGE_PIN B15 IOSTANDARD LVCMOS33 } [get_ports {spi_clk}] ;# JB3
#set_property -dict { PACKAGE_PIN B16 IOSTANDARD LVCMOS33 } [get_ports {spi_miso}];# JB4
#set_property -dict { PACKAGE_PIN C15 IOSTANDARD LVCMOS33 } [get_ports {cs_out}]   ;# JB9

# Pmod power/ground positions are fixed board connections, not FPGA package
# pins, so they have no XDC entries.

# Clock-domain crossing intent.
# PCB.vhd uses two-stage toggle synchronizers in each direction. The 16-bit
# sample bus is held stable by that request/acknowledge protocol while tx_word
# captures it. These deliberate inter-clock crossings are excluded below;
# separate asynchronous board-control/output exceptions follow afterward.
set cdc_sync_regs [get_cells -quiet -hierarchical [list \
    sample_req_meta_u_reg sample_req_sync_u_reg \
    sample_ack_meta_a_reg sample_ack_sync_a_reg]]
set_property ASYNC_REG TRUE $cdc_sync_regs

set req_meta_d [get_pins -quiet -hierarchical sample_req_meta_u_reg/D]
set ack_meta_d [get_pins -quiet -hierarchical sample_ack_meta_a_reg/D]
set sample_bus_regs [get_cells -quiet -hierarchical *sample_word_adc_reg*]
set tx_word_regs [get_cells -quiet -hierarchical *tx_word_reg*]

set_false_path -to $req_meta_d
set_false_path -to $ack_meta_d
set_false_path -from $sample_bus_regs -to $tx_word_regs

# These are asynchronous physical controls/protocol outputs, not source-
# synchronous interfaces with external timing relationships.
set_false_path -from [get_ports {reset_in start_in}]
set_false_path -to [get_ports {ready_out txd_out}]
